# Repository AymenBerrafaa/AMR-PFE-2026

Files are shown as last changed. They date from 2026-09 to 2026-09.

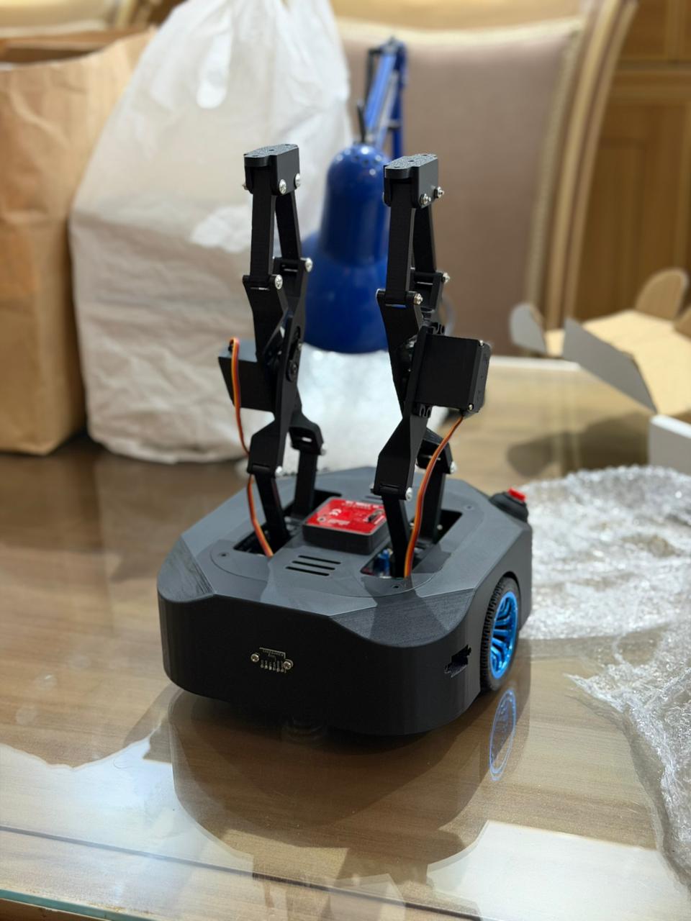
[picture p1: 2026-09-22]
Photos/WhatsApp Image 2026-05-21 at 2.42.04 PM.jpeg

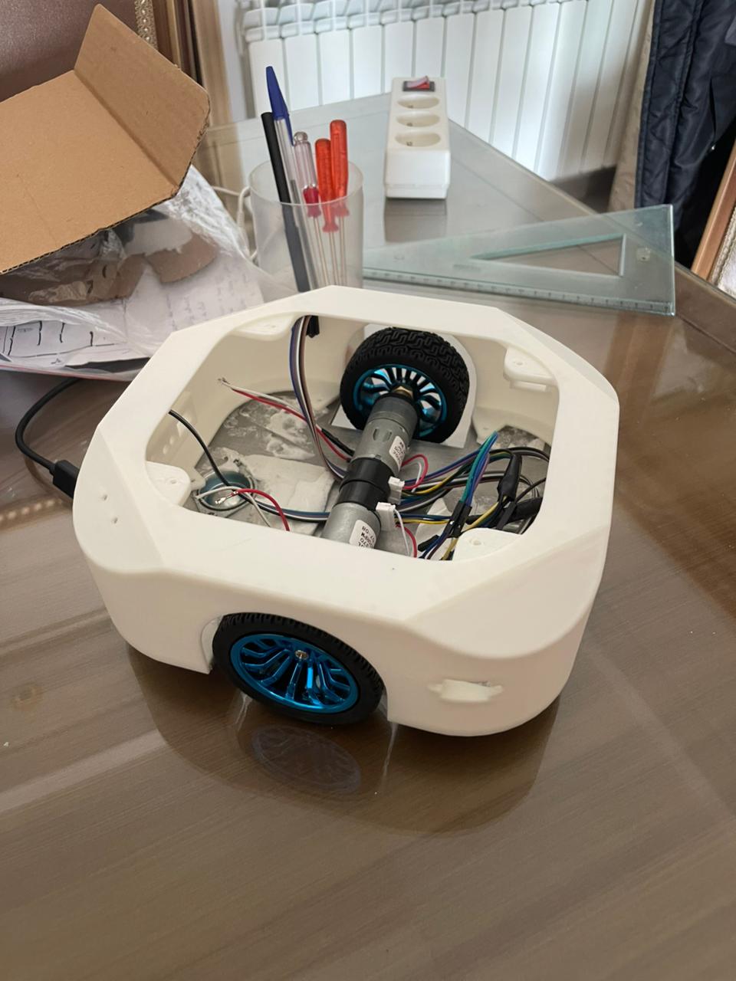
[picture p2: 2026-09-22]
Photos/WhatsApp Image 2026-05-19 at 1.59.03 PM (2).jpeg

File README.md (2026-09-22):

# Autonomous Warehouse AMR — Industrie 4.0

An autonomous mobile robot (AMR) designed for smart warehouse logistics and material transportation. The robot autonomously navigates a grid-based warehouse environment, detects obstacles and walls, plans optimal paths, and performs automated delivery tasks.

Built around an ESP32-S3, the system combines distance sensing, wheel odometry, inertial orientation, RFID identification, motor control, and a real-time web dashboard into a single autonomous platform.

WhatsApp Image 2026-05-26 at 4 40 33 PM WhatsApp Image 2026-05-26 at 2 25 29 PM (1)



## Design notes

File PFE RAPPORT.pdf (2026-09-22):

Rapport de Stage de Fin
d’Etudes

A .U : 2025 / 2026

République Tunisienne
Ministère de l’Enseignement Supérieur,
et de la Recherche Scientifique

Université de Gabès
Institut Supérieur des Systèmes Industriels de Gabès

# RAPPORT PFE

Présenté à

### l’Institut Supérieur des Systèmes Industriels de Gabès

### Dans la discipline

# LICENCE EN EEA

## Spécialité : Systèmes Automatisés et Réseaux Industriels

Réalisé(e) Par

## BERRAFAA Aymen

## Sujet : Etude, Conception et Réalisation d'un prototype de robot mobile autonome pour la

logistique en entrepôt.

Soutenu le 17 juin 2026, devant le jury composé de :

Mme. Hanen CHAOUCH (Maître de conférences) | Président
Mme. Rim KILANI (Maître-assistante) | Rapporteur
Mme. Rafika HARABI (Assistante) | Encadreur

Je dédie ce projet :

Je dédie ce projet, fruit de vos sacrifices, de vos prières silencieuses et de vos nuits sans sommeil. Merci pour votre amour inconditionnel et pour vos conseils qui ont guidé mes pas. Vous avez été ma lumière dans les moments d’incertitude, et c’est grâce à votre soutien que j’ai pu surmonter chaque obstacle. Ce succès est autant le vôtre que le mien.
A mon frère Ahmed,

Merci d'être le pilier que tu es pour moi. Pour ton écoute, tes encouragements et même tes remarques qui m'ont fait grandir. Tu restes mon meilleur allié et un exemple de réussite. Que ce projet soit un témoignage de ma gratitude envers toi.

A mes chères sœurs Mariem, Zaineb et Malak,

Votre présence a été ma plus grande force. Merci pour vos rires qui ont dissipé mes doutes, pour vos conseils francs qui m'ont guidé, et pour votre soutien inconditionnel dans chaque épreuve. Vos encouragements et votre soutien moral tout au long de mes études ont été ma boussole.

A toute ma famille,

A tous mes autres ami(e)s,

A tous ceux que j’aime et ceux qui m’aiment.

, Aymen

# Remerciements

Avant de commencer la présentation de ce rapport, je tiens à exprimer ma profonde

gratitude envers Dieu Tout-Puissant, qui m’a accordé la force, la santé et la persévérance

nécessaires pour mener à bien ma période de stage et finaliser ce projet.

Je tiens à remercier sincèrement Madame Rafika HARABI, mon encadrante universitaire,

pour son accompagnement précieux, ses conseils éclairés et sa disponibilité tout au long de

cette expérience. Son encadrement rigoureux et bienveillant a été un véritable soutien dans la

réalisation de ce travail.

Je remercie également Monsieur Hafedh YAHMED, mon encadrant professionnel, pour

son accueil chaleureux au sein de l’entreprise, ainsi que pour ses orientations pertinentes et

les moyens mis à ma disposition tout au long de cette expérience professionnelle.

Ma gratitude va également à l’ensemble de l’équipe de la société RMG, pour leur accueil,

leur collaboration et l’environnement de travail motivant qu’ils ont su créer. Cette expérience

a été pour moi particulièrement enrichissante, tant sur le plan technique que personnel.

Enfin, je tiens à remercier chaleureusement les membres du jury pour l’attention qu’ils

porteront à l’évaluation de ce travail, ainsi que tous les enseignants de l’Institut supérieur des

systèmes industriels de Gabès pour la qualité de leur enseignement, leur accompagnement et

leur contribution à ma formation tout au long de mon parcours académique.

# Sommaire

3.1.8. Module NFC/RFID PN532 | 52
3.1.9. Régulateur abaisseur LM2596 | 53
3.1.10. Moteur JGA25-370 12V 500 RPM avec encodeur | 54
3.1.11. Batterie Li-ion 18650 Samsung 3400 mAh avec BMS 3S | 55
4. Conception mécanique | 56
4.1. Présentation de système sur le logiciel « SolidWorks » | 56
4.2. Conception du robot | 56
4.3. Conception du mécanisme de levage | 58
4.4. Conception du support de la maquette | 59
5. Conception logicielle | 60
5.1. Organisation des tâches | 60
5.2. Asservissement par correcteur PID | 61
5.2.1. Modélisation et schéma fonctionnel | 62
5.2.2. Correcteur PID et choix retenu | 62
5.3. Gestion de la batterie et retour station | 64
5.4. Communication et supervision | 64
6. Algorithme de fonctionnement | 65
6.1. Étude comparative des algorithmes de navigation | 65
6.1.1. Algorithme Flood Fill | 65
6.1.2. Algorithme A* | 66
6.1.3. Algorithme Dijkstra | 67
6.1.4. Algorithme SLAM | 67
6.2. Algorithme de navigation | 69
7. Dimensionnement du système | 76
7.1. Paramètres cinématiques de déplacement | 76
7.1.1. Vitesse linéaire de navigation | 76
7.1.2. Résolution odométrique | 76
7.1.3. Précision angulaire | 77
7.2. Dimensionnement mécanique | 78
7.2.1. Estimation de la masse totale | 78
7.2.2. Vérification de la force de traction | 79
7.3. Dimensionnement du mécanisme de levage | 79
7.3.1. Géométrie du mécanisme en ciseaux | 79
7.3.2. Analyse des forces et validation du servomoteur | 80
7.4. Bilan de puissance et autonomie | 81
7.4.1. Puissance consommée par sous-système | 81

7.4.2. Calcul de l'autonomie | 82
7.5. Vérification de la stabilité statique | 83
7.6. Récapitulatif général du dimensionnement | 84
8. Conclusion | 84
CHAPITRE IV : Réalisation et étude économique | 86
1. Introduction | 86
2. Réalisation du prototype | 86
2.1. Présentation du prototype | 86
2.2. Assemblage mécanique | 87
2.2.1. Fabrication du châssis | 87
2.2.2. Impression 3D du cadre supérieur | 87
2.2.3. Intégration des moteurs et des roues | 89
2.2.4. Mécanisme de levage en ciseaux | 89
2.2.5. Impression 3D des connecteurs de maquette | 91
2.3. Intégration électronique | 92
2.3.1. Réalisation de la carte électronique dédiée | 92
2.3.2. Raccordement des capteurs et actionneurs | 94
2.3.3. Gestion de l'alimentation | 94
2.4. Vue d'ensemble du prototype assemblé | 95
2.5. Interface de supervision | 96
2.5.1. Architecture de l'interface | 96
2.5.2. Panneau de navigation et de cartographie | 97
2.5.3. Panneau de télémétrie et de sécurité | 98
2.5.4. Journal d'événements | 99
3. Validation et tests | 99
3.1. Tests de déplacement | 99
3.2. Tests de détection d'obstacles | 100
3.3. Tests de sécurité environnementale | 101
3.4. Résultats obtenus | 101
4. Difficultés rencontrées et solutions | 102
4.1. Problèmes matériels | 102
4.2. Problèmes logiciels | 102
5. Étude économique | 103
5.1. Analyse économique | 104
6. Conclusion | 105
Conclusion générale | 107

# Liste des figures

Figure 44 : Régulateur abaisseur LM2596 | 53
Figure 45 : Schéma de Brochage du LM2596 | 53
Figure 46 : Schéma de Brochage du moteur | 54
Figure 47 : Moteur JGA25-370 12V 500 RPM avec encodeur | 54
Figure 48 : BMS 3S | 55
Figure 49 : Support Batterie | 55
Figure 50 : Batterie Li-ion 18650 Samsung 3400 mAh 8A | 55
Figure 51 : Interface SolidWorks | 56
Figure 52 : Châssis principal | 57
Figure 53 : Dimensionnement de châssis principal | 57
Figure 54 : Le cadre supérieur du robot | 57
Figure 55 : Modélisation mécanique | 58
Figure 56 : Pièce centrale inférieure (3) | 58
Figure 57 : Bras gauche (2) | 58
Figure 58 : Pièce centrale | 58
Figure 59 : Base de fixation | 58
Figure 60 : Support haut/bas (1) | 58
Figure 61 : Bras droit (2) | 58
Figure 62 : Panneaux MDF | 59
Figure 63 : Maquette 4×4 | 59
Figure 64 : Connecteur d’angle | 59
Figure 65 : Connecteur en T | 59
Figure 66 : Connecteur droit | 59
Figure 67 : Architecture logicielle multicouche du robot | 60
Figure 68 : Initialisation et cartographie de l’entrepôt | 72
Figure 69 : Boucle de mission logistique (partie 1/2) | 73
Figure 70 : Boucle de mission logistique (partie 2/2) | 74
Figure 71 : Sécurité et supervision parallèles | 75
Figure 72 : Le prototype modélisé sous SolidWorks | 86
Figure 73 : Châssis aluminium usiné | 87
Figure 74 : vue de dessus avec alésages moteurs et roues folles | 87
Figure 75 : Cadre supérieur après peinture | 88
Figure 76 : Cadre supérieur imprimé (vue brute après impression) | 88
Figure 77 : Préparation du slicing sous Creality Slicer | 88
Figure 78 : Intégration des moteurs et des roues sur le châssis | 89
Figure 79 : Mécanisme de levage en ciseaux | 90
Figure 80 : Position haute | 90
Figure 81 : Position basse | 90
Figure 82 : Connecteurs de maquette | 91
Figure 83 : La maquette d'expérimentation 4×4 assemblée | 91
Figure 84 : PCB dédié conçu sous Altium Designer | 92
Figure 85 : Face supérieure de la carte | 93
Figure 86 : Intégration électronique du robot | 94
Figure 87 : Vue de côté avec mécanisme de levage | 95
Figure 88 : Vue de dessus - intégration interne | 95

Figure 89 : Vue du robot assemblé | 96
Figure 90 : Vue générale du tableau de bord de supervision | 97
Figure 91 : Panneau de cartographie et visualisation de la grille 4×4 | 98
Figure 92 : Panneau de télémétrie et de sécurité environnementale | 98
Figure 93 : Panneau de journal d'événements | 99
Figure 94 : Robot lors des tests de déplacement sur la maquette | 100
Figure 95 : Robot en cours de validation des capteurs | 100
Figure 96 : Test de sécurité environnementale | 101

# Liste des tableaux

# Liste des abréviations

AGV : Automated Guided Vehicle (Véhicule à Guidage Automatique)

AMR : Autonomous Mobile Robot (Robot Mobile Autonome)

ADC : Analog-to-Digital Converter (Convertisseur Analogique-Numérique)

BFS : Breadth-First Search (Parcours en Largeur d'abord) – algorithme d'exploration

BMS : Battery Management System (Système de Gestion de Batterie)

CAO : Conception Assistée par Ordinateur

CNC : Computer Numerical Control (Commande Numérique par Calculateur)

CPR : Counts Per Revolution (Impulsions Par Tour) – résolution d'un encodeur

DC : Direct Current (Courant Continu)

DFS : Depth-First Search (Parcours en Profondeur d'abord) – algorithme d'exploration

DXF : Drawing Exchange Format – format d'échange de fichiers CAO 2D

ESP32 : Microcontrôleur double cœur Xtensa LX7 @ 240 MHz développé par Espressif Systems

FAST : Function Analysis System Technique – méthode d'analyse fonctionnelle interne

FreeRTOS : Free Real-Time Operating System – système d'exploitation temps réel open source

GPIO : General Purpose Input/Output (Entrée/Sortie à Usage Général)

GPL : Gaz de Pétrole Liquéfié – gaz détecté par le capteur MQ-5

HAL : Hardware Abstraction Layer (Couche d'Abstraction Matérielle)

HTML : HyperText Markup Language – langage de balisage pour les interfaces web

I²C : Inter-Integrated Circuit – protocole de communication série synchrone (bus 2 fils)

IDE : Integrated Development Environment (Environnement de Développement Intégré)

IMU : Inertial Measurement Unit (Centrale Inertielle) – capteur accéléromètre + gyroscope

IoT : Internet of Things (Internet des Objets)

ISR : Interrupt Service Routine (Routine de Traitement d'Interruption)

JSON : JavaScript Object Notation – format léger d'échange de données

LED : Light-Emitting Diode (Diode Électroluminescente)

LIDAR : Light Detection And Ranging – capteur de distance à faisceau laser tournant

MDF : Medium-Density Fibreboard (Panneau de Fibre à Densité Moyenne)

MQTT : Message Queuing Telemetry Transport – protocole de messagerie machine-à-machine

NFC : Near Field Communication (Communication en Champ Proche)

PCB : Printed Circuit Board (Circuit Imprimé)

PETG : Polyethylene Terephthalate Glycol – matériau d'impression 3D résistant et flexible

PID : Proportionnel-Intégral-Dérivé – correcteur de régulation automatique

PLA : Polylactic Acid (Acide Polylactique) – matériau d'impression 3D biodégradable

PSRAM : Pseudo-Static RAM – mémoire RAM externe pseudo-statique intégrée à l'ESP32-S3

PWM : Pulse Width Modulation (Modulation de Largeur d'Impulsion)

RAM : Random Access Memory (Mémoire Vive)

RFID : Radio Frequency Identification (Identification par Radio-Fréquence)

RMG : Rebobinage Moteur & Groupe Électrogène Gabès – entreprise d'accueil du stage

ROS : Robot Operating System – système d'exploitation pour la robotique

RPM : Revolutions Per Minute (Tours Par Minute)

SAV : Service Après-Vente

SLAM : Simultaneous Localization And Mapping (Localisation et Cartographie Simultanées)

SPI : Serial Peripheral Interface – protocole de communication série synchrone (bus 4 fils)

SRAM : Static Random Access Memory (Mémoire Vive Statique)

SSID : Service Set Identifier – nom d'un réseau Wi-Fi

ToF : Time of Flight (Temps de Vol) – technologie de mesure de distance laser

UART : Universal Asynchronous Receiver-Transmitter – protocole de communication série asynchrone

URL : Uniform Resource Locator – adresse d'une ressource sur le web

USB : Universal Serial Bus – interface de connexion et d'alimentation

Wi-Fi : Wireless Fidelity – réseau local sans fil IEEE 802.11

WMS : Warehouse Management System (Système de Gestion d'Entrepôt)

# Introduction générale

Introduction générale

Etude, conception et réalisation d'un prototype de robot mobile autonome pour la logistique en entrepôt

# Introduction générale

L’évolution constante de l’industrie 4.0 impose aujourd’hui une gestion des flux de

marchandises de plus en plus rapide et précise. Dans ce contexte, la manutention manuelle et

le transport interne de matériel représentent des défis opérationnels majeurs, impactant

directement la productivité et la sécurité. Le déplacement répétitif de charges lourdes prend du

temps, fatigue physiquement les opérateurs et accroît le risque d'accidents du travail.

Au sein des centres logistiques modernes, l’enjeu n'est plus seulement de déplacer une

charge, mais d'optimiser le flux tout en garantissant une sécurité totale. Les méthodes de

transport traditionnelles manquent souvent de flexibilité et de réactivité face aux changements

dynamiques de l’environnement. Dès lors, l’intégration de la robotique mobile autonome

devient une solution incontournable pour fluidifier la logistique, réduire la pénibilité des tâches

et assurer une surveillance constante des zones de stockage.
Ce Projet de Fin d’Études, réalisé en partenariat avec la société 'RMG', a pour but de

concevoir et réaliser un prototype de robot mobile autonome capable de naviguer de manière

intelligente, de cartographier son environnement et d'assurer le transfert de marchandises en

toute autonomie. Au-delà du simple transport, ce prototype intègre des fonctionnalités de

supervision avancées, telles que la gestion intelligente de l'énergie et la surveillance de

paramètres environnementaux (détection de gaz, incendie et température) pour garantir la

sécurité des infrastructures.

Ce rapport est organisé en quatre chapitres, précédés de la présentation de l'entreprise

d'accueil 'RMG' et du cahier des charges, et clôturés par une conclusion générale. Le premier

chapitre présente l'étude bibliographique des robots mobiles industriels et autonomes, ainsi

qu'un état de l'art des technologies de navigation indoor. Le deuxième chapitre est consacré à

l'analyse fonctionnelle du système et au choix justifié des solutions techniques retenues. Le

troisième chapitre détaille l'étude et la conception du prototype, en couvrant l'architecture

matérielle et logicielle, ainsi que le dimensionnement complet du système. Le quatrième

chapitre présente la réalisation physique du prototype, les tests de validation effectués sur la

maquette 4×4, l'analyse des résultats obtenus ainsi que l'étude économique du projet.

# Présentation de la société

Présentation de la société

# Présentation de la société

## 1. Présentation Générale de l'Entreprise

RMG est une entreprise tunisienne spécialisée dans le domaine de la maintenance

électromécanique, notamment la fabrication, le bobinage et le rebobinage de moteurs et de

générateurs, basée à Gabès. Depuis sa création, RMG joue un rôle important dans le secteur

industriel tunisien, contribuant à la pérennité des équipements électriques et à la promotion

d’une infrastructure de qualité. Son expérience témoigne de sa fiabilité et de son engagement

envers l’innovation et la performance technique au service de l'industrie. Elle est située à la

Rue Elwehda, dans le gouvernorat de Gabes (6000). Avec une expertise solide dans son

domaine, RMG fournit des services de haute qualité aux professionnels. L’entreprise peut être

contactée par téléphone au 58 821 009, par fax au 74 299 650, permet également de découvrir

ses produits et services.

## 2. Activités et Produits

L'activité de RMG s'articule autour de solutions techniques complètes pour les machines

électriques, allant du diagnostic à la remise en neuf. Ses principales expertises incluent :

Bobinage et Rebobinage : Remise en état complète des bobinages de moteurs électriques

(BT/HT), d'alternateurs et de transformateurs, en respectant les classes d'isolation les plus

strictes.
Maintenance Électromécanique : Diagnostic de pannes, expertise mécanique, équilibrage

dynamique et remplacement de pièces d’usure (roulements, arbres, ventilateurs).

Fabrication et Montage : Conception de solutions spécifiques et assemblage de moteurs

ou de générateurs adaptés aux besoins des clients industriels.

Figure 1 : Logo de RMG

Présentation de la société

Vente et Distribution : Fourniture de moteurs neufs et de pièces de rechange certifiées

pour assurer la continuité de service des parcs machines.

RMG collabore avec des partenaires technologiques pour garantir des matériaux (fil de

cuivre, isolants, vernis) répondant aux normes internationales de sécurité et de rendement.

## 3. Marché et Positionnement

RMG cible principalement trois segments clés du marché tunisien : les complexes

industriels lourds (cimenteries, usines chimiques), les entreprises de gestion des eaux et de

l'énergie, ainsi que les exploitations agricoles mécanisées. Cette diversification de clientèle lui

permet de couvrir un large spectre de besoins en maintenance, en bobinage et en fourniture de

machines électriques.

Sur un marché concurrentiel, RMG se distingue par son expertise technique et ses

partenariats avec des fournisseurs de composants électromécaniques. Elle fait face à la

concurrence d’autres ateliers de maintenance locaux, ainsi qu’à la pression des constructeurs

internationaux de moteurs qui opèrent directement en Tunisie. Pour maintenir son

positionnement, l’entreprise mise sur la qualité de ses interventions, la fiabilité de ses services

après-vente (SAV) et sa capacité à répondre aux exigences spécifiques des professionnels de

l'industrie et de la production d'énergie.

Cette stratégie lui permet de se positionner comme un acteur crédible et compétitif dans un

secteur en constante évolution, où la performance technique et la réactivité jouent un rôle

déterminant dans le choix des partenaires.

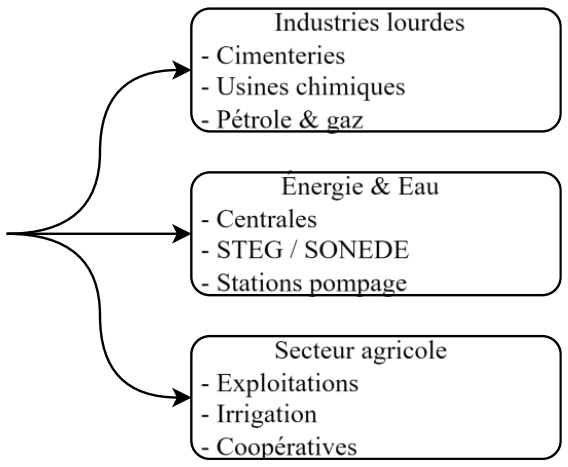
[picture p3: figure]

Figure 2 : Principaux marchés cibles de RMG

# Cahier des charges

Cahier Des Charges

# CAHIER DES CHARGES

## Sujet :

Etude, conception et réalisation d'un prototype de robot mobile autonome pour la logistique

en entrepôt.

## Objectif :

L'objectif principal de ce projet est de développer un prototype de robot capable de :

Automatiser le transport de marchandises entre différentes zones (stockage, réception) pour

fluidifier la logistique.

Reconnaître et mémoriser son environnement de manière autonome afin d'optimiser ses

déplacements.

Garantir une sécurité totale grâce à la surveillance environnementale (détection de gaz,

incendie et température).

Assurer une gestion intelligente de l'énergie via un système de recharge automatique et une

supervision en temps réel.

## Travail demandé :

- Étude approfondie des besoins logistiques en milieu industriel, en prenant en compte

les types de charges à transporter et les contraintes de navigation en espace restreint.

- Recherche et sélection des technologies de navigation (capteurs, cartographie) et de

traction les plus appropriées, en tenant compte de leur efficacité, durabilité et coût.

- Conception du robot sur le logiciel SolidWorks.
- La configuration mécanique et électronique.
- Intégration des algorithmes d’automatisation, de cartographie et de missions.
- Réalisation d'un prototype fonctionnel, avec des tests approfondis pour vérifier la

précision de la navigation et la fiabilité du transport.

- Mise en place d'un système de supervision et de communication entre l’utilisateur et le

robot (interface de suivi, Wi-Fi, etc.).

- Documentation de toutes les étapes du projet (Les spécifications techniques, les

résultats des tests, les schémas de conception, etc.).

# CHAPITRE Ⅰ : Étude bibliographique

Etude Bibliographique

# CHAPITRE Ⅰ : Étude bibliographique

## 1. Introduction

Cette étude explore les solutions automatisées pour le transport de charges industrielles,

telles que les Robots Mobiles Autonomes, afin d’offrir une alternative efficace et sécurisée aux

méthodes de manutention manuelles. Bien que la robotique mobile gagne en popularité dans

les domaines logistiques, manufacturiers et de maintenance, des défis persistent : l'optimisation

de la navigation autonome, la gestion énergétique en flux continu et l'adaptation aux

environnements encombrés des entrepôts.

L’objectif est d’analyser les technologies existantes, leurs limites et les innovations

potentielles pour concevoir un prototype robuste et polyvalent. Ce chapitre synthétise les

solutions actuelles, les technologies émergentes de navigation et les meilleures pratiques

industrielles, afin de guider le développement d’un robot fiable, réduisant la pénibilité du travail

et les risques d’incidents matériels.

## 2. Généralités sur les robots mobiles autonomes

### 2.1. Définition d'un robot mobile autonome (AMR)

Le robot mobile autonome est un système automatisé intelligent conçu pour transporter et

manœuvrer des charges dans des environnements dynamiques sans intervention humaine

constante [1]. Contrairement aux systèmes guidés simples, l'AMR utilise des capteurs de

précision (LIDAR, ultrasons, infrarouge) et des algorithmes de cartographie avancés pour

calculer ses propres trajectoires. Ses principaux atouts incluent une flexibilité totale face aux

obstacles, une grande maniabilité dans les espaces restreints des ateliers, ainsi qu'une interface

logicielle permettant un suivi en temps réel.

Ce type de robot trouve des applications cruciales dans de nombreux secteurs : dans la

logistique pour le déplacement de bacs de pièces, dans l'industrie pour le transfert de moteurs

ou de générateurs entre les zones de stockage et de bobinage, et dans les centres de distribution.

Il offre une solution pratique qui améliore la productivité globale tout en garantissant une

sécurité accrue grâce à ses systèmes de détection intégrés.

Etude Bibliographique

### 2.2. Historique des robots mobiles

L’histoire de la mécanisation du transport remonte à l’ère industrielle, lorsque les premiers

convoyeurs et chariots motorisés ont commencé à soulager l’homme des travaux de force. Les

premières innovations du 19ème siècle, bien qu'efficaces pour l'époque, restaient des machines

massives et fixes, limitées à des tâches répétitives sur rails.

Le début du 20ème siècle a marqué une révolution avec l’électrification des chariots

élévateurs, permettant une mobilité accrue dans les usines. Vers le milieu du siècle, les premiers

AGV (Automated Guided Vehicles) ont fait leur apparition, capables de suivre des lignes

magnétiques ou des câbles enterrés. Aujourd’hui, les AMR comme celui développé pour ce

projet incarnent l’aboutissement de cette évolution. Dotés d’intelligence artificielle et d’une

autonomie décisionnelle complète, ils répondent avec précision aux besoins de l'industrie 4.0.

### 2.3. Constituants d'un robot mobile autonome

Un robot mobile est un système complexe composé de plusieurs sous-systèmes [1] qui

travaillent en synergie pour garantir ses performances :

1) Système de traction :

Le robot utilise des moteurs électriques haute performance offrant un couple élevé et

une excellente efficacité énergétique pour déplacer des charges lourdes. La transmission

mécanique optimise le transfert de puissance vers les roues, garantissant une traction fiable

et économe en énergie.

Figure 3 : Robot mobile autonome

Etude Bibliographique

2) Système de mobilité :

L'architecture intègre des roues motorisées permettant des manœuvres précises dans

les espaces confinés. La configuration peut varier selon le terrain (roues standards ou

omnidirectionnelles).

3) Système de contrôle :

Le robot est piloté par une unité centrale équipée de processeurs embarqués

performants qui coordonnent l'ensemble des opérations. Des algorithmes avancés de

navigation lui permettent d'analyser son environnement en temps réel et d'ajuster sa

trajectoire de manière autonome.

4) Système de détection :

Le robot s'appuie sur une combinaison de capteurs (LIDAR, ultrasons, infrarouge)

pour cartographier son environnement et éviter les obstacles avec précision. Des caméras

haute résolution complètent ce système en offrant une vision en temps réel et en permettant

des fonctions avancées comme la reconnaissance d'objets ou le suivi de balises,

garantissant une navigation sécurisée et autonome dans des environnements complexes.

5) Source d'énergie :

Le robot est équipé de batteries lithium-ion haute performance offrant une autonomie

optimale, couplées à un système de gestion énergétique (BMS) qui régule précisément la

consommation et protège contre les surcharges.

6) Système d'interfaçage :

Le système propose une interface intuitive via écran tactile ou application mobile,

permettant un contrôle aisé et un suivi en temps réel des opérations. La connectivité sans

fil (Wi-Fi/Bluetooth) assure une communication fluide avec les opérateurs et une parfaite

intégration dans les écosystèmes logistiques intelligents.

### 2.4. Les types de robots de transport industriel

Les robots de transport sont conçus pour déplacer des charges, comme des bacs, des

palettes ou des composants. Ces robots se différencient par leurs technologies, leurs capacités

et leurs applications. Voici une classification des principaux types de robots utilisés :

Etude Bibliographique

### 2.4.1. Robots de manutention assistés (semi-automatique)

Ces robots nécessitent une intervention humaine pour leur guidage, mais ils fournissent une

assistance motorisée pour réduire l’effort physique.

- Caractéristiques :

Ces systèmes d'assistance électrique offrent une solution simple et économique pour

déplacer des charges lourdes allant de 500 kg à 2 000 kg. Particulièrement adaptés aux

environnements industriels comme les entrepôts, ils combinent puissance et efficacité pour

faciliter les opérations de manutention tout en réduisant l'effort physique requis.

Exemple et utilisation : Transpalettes électriques à accompagnement : Un système manuel

assisté pour déplacer des palettes en zone de réception.

Avantages et limitations fonctionnelles :

Les systèmes semi-automatisés présentent des caractéristiques fonctionnelles notables.

D'une part, ils permettent une réduction substantielle de la sollicitation physique des opérateurs

lors des opérations de manutention, tout en offrant une interface de contrôle intuitive ne

nécessitant qu'une formation minimale. Leur architecture mécanique simplifiée se traduit par

des coûts d'acquisition et de maintenance inférieurs aux solutions entièrement automatisées.

D'autre part, ces systèmes présentent des limitations opérationnelles significatives. Leur

fonctionnement requiert une supervision humaine continue et leur capacité de charge reste

inférieure à celle des systèmes robotisés avancés. Par ailleurs, leur performance est optimale

Figure 4 : Chariot élévateur semi-automatique

Etude Bibliographique

sur surfaces planes et régulières, avec une efficacité décroissante dans des environnements

topographiquement complexes.

- Prix et facteurs d’influence

De 1 500 € à 5 000 €. Les facteurs influençant le prix sont la capacité de charge, l'autonomie

de la batterie et la marque du fabricant (ex : Toyota, Jungheinrich).

### 2.4.2. Robots de manutention télécommandés

Ces robots sont pilotés à distance par un opérateur via une console de commande. Ils

permettent de manipuler des charges lourdes dans des zones étroites ou dangereuses sans

contact direct.

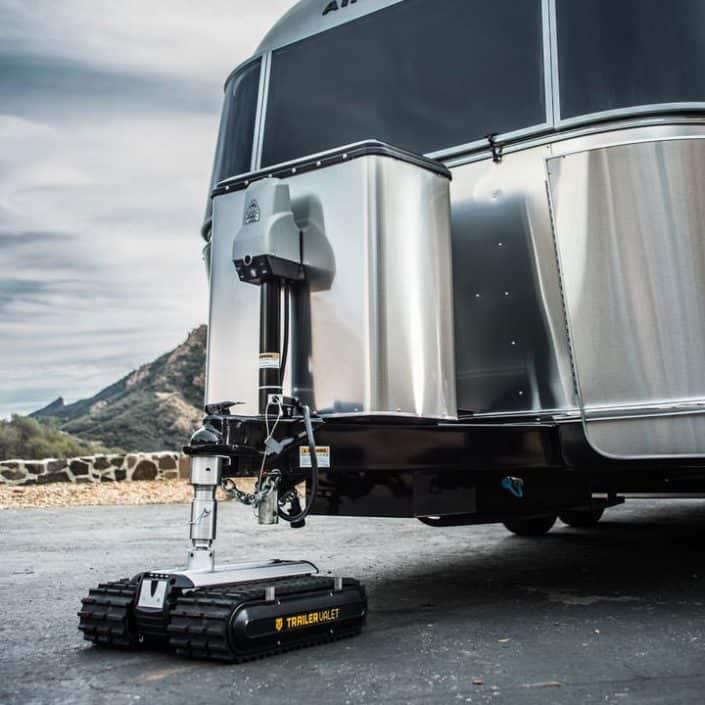
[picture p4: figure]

Figure 5 : Robots de traction télécommandés

- Caractéristiques techniques et applications

Ces systèmes se distinguent par leur capacité à opérer à distance via différents protocoles

de communication (Wi-Fi, Bluetooth, radiofréquence), tout en conservant une excellente

adaptabilité aux divers types de terrains. Leur conception mécanique avancée permet la

manipulation de charges substantielles (500 à 5000 kg) avec une précision de manœuvre

remarquable, particulièrement dans des espaces confinés.

Ces systèmes robotisés trouvent leur utilité dans plusieurs contextes opérationnels. Leurs

caractéristiques techniques les rendent particulièrement adaptés à :

Etude Bibliographique

- Manutention logistique : Déplacement précis de remorques en espaces restreints (zones

de chargement, centres logistiques)

- Secteur nautique/camping : Positionnement de bateaux/caravanes sur terrains accidentés
- Chantiers industriels : Manipulation d'équipements lourds (jusqu'à 5 tonnes) là où les

engins traditionnels peinent à manœuvrer

Exemple : Trailer Valet RVR

- Avantages et limites :

Les robots de traction télécommandés offrent des avantages significatifs, notamment un

contrôle précis particulièrement adapté aux espaces restreints, une capacité à tracter des charges

lourdes jusqu'à plusieurs tonnes, et une grande polyvalence d'utilisation sur différents types de

terrains. Leur conception compacte facilite par ailleurs leur transport et leur déploiement sur

divers sites.

Cependant, ces systèmes présentent certaines limitations : ils dépendent entièrement de leur

télécommande, nécessitant ainsi une gestion attentive des batteries, et peuvent s'avérer difficiles

à manipuler. De plus, leur coût d'acquisition reste plus élevé que celui des modèles manuels

assistés.

- Prix et facteurs d’influence :

De 5 000 € à 15 000 € les facteurs influençant le prix sont (Puissance de traction (capacité

en kg), Technologie de télécommande (filaire ou sans fil), Robustesse et durabilité (militaire

ou civil).

### 2.4.3. Véhicules à Guidage Automatique (AGV)

Les AGV suivent des chemins fixes prédéfinis par des infrastructures au sol (bandes

magnétiques, rails ou balises), pour fonctionner sans intervention humaine directe. Ils

constituent une solution standard pour le transport de charges lourdes

Etude Bibliographique

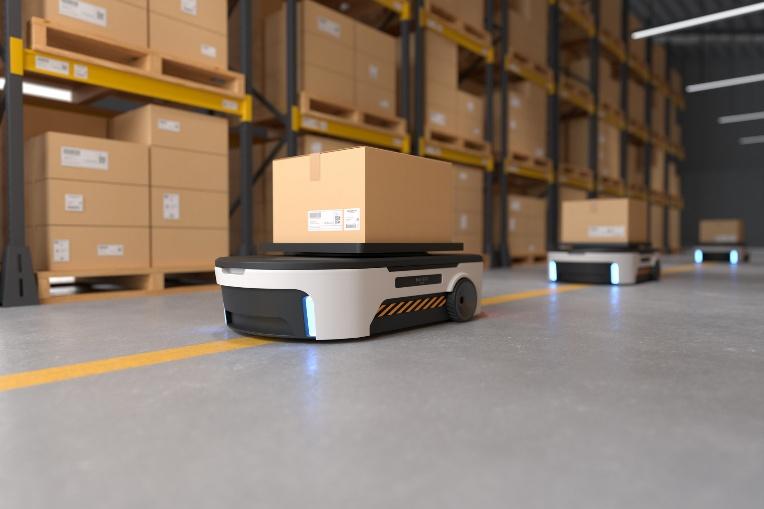
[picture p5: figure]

Figure 6 : AGV industriel suivant une ligne magnétique

- Caractéristiques techniques et applications

Ces systèmes se distinguent par leur navigation dépendante d’une infrastructure physique

au sol (bandes magnétiques, rails, fils inductifs ou balises laser). Leur conception mécanique

est optimisée pour la stabilité et la puissance de traction (500 kg à 10 tonnes).

Les AGV trouvent leur utilité principale dans :

- Lignes de production : Transport de composants entre des stations de travail fixes.
- Entrepôts automatisés : Déplacement de palettes lourdes sur des boucles prédéfinies.
- Secteur automobile : Acheminement de châssis le long des chaînes d'assemblage.
- Exemple : Kiva Systems (premières générations), AGV à guidage par bande magnétique.
- Avantages et limites :

Les AGV offrent une grande fiabilité et une excellente répétabilité pour les tâches simples.

Ils permettent de sécuriser les flux de transport massifs à un coût de maintenance prévisible.

Cependant, ils manquent de flexibilité : toute modification du trajet nécessite des travaux

coûteux sur l'infrastructure. De plus, ils s'arrêtent net devant un obstacle sans pouvoir le

contourner, ce qui peut paralyser l'ensemble du flux logistique.

- Prix et facteurs d’influence :

De 15 000 € à 45 000 €. Les facteurs influençant le prix sont la capacité de charge, le type

d'infrastructure de guidage requis et les dispositifs de sécurité (scanners laser).

Etude Bibliographique

### 2.4.4. Robots Mobiles Autonomes (AMR)

L'AMR constitue une rupture technologique majeure grâce à son intelligence embarquée

et sa capacité de décision en temps réel.

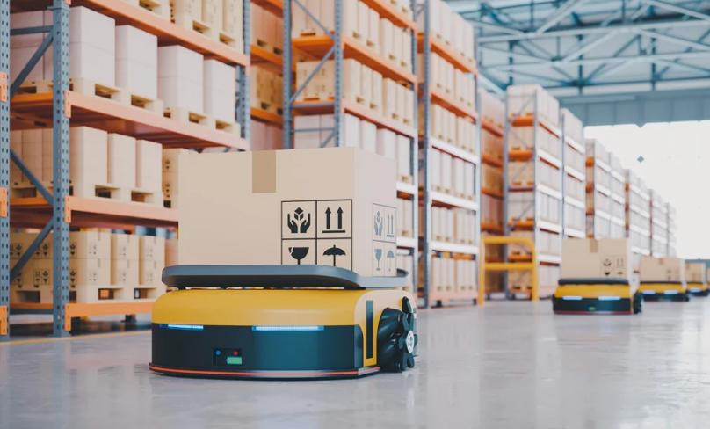
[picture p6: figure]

- Caractéristiques techniques et applications

Ces systèmes intègrent une intelligence artificielle embarquée capable de cartographie

simultanée et de localisation. Ils utilisent une fusion de capteurs avancés (LIDAR, caméras 3D,

ultrasons, encodeurs) pour interpréter leur environnement en temps réel. Leur capacité de

charge varie de 100 kg à 1 500 kg avec une agilité exceptionnelle.

Les AMR sont particulièrement adaptés à :

- Logistique en entrepôt : Gestion autonome des stocks (ajout/retrait) avec mise à jour en

temps réel des bases de données.

- Préparation de commandes : Guidage vers les étagères et transport de bacs dans des allées

encombrées.

- Industrie 4.0 : Transport multisites où le robot doit emprunter des ascenseurs et contourner

des obstacles imprévus (humains, palettes mal placées).

- Exemple : MiR100 (ou MiR250) de la société Mobile Industrial Robots (MiR). [W5]
- Avantages et limites :

L’avantage majeur réside dans la flexibilité totale et la gestion intelligente des

marchandises. Le robot sait précisément ce qu'il transporte, d'où il vient et où il va, surpassant

Figure 7 : AMR logistique intelligent

Etude Bibliographique

la gestion humaine en termes de précision d'inventaire. Il permet un gain de temps considérable

en recalculant instantanément ses trajectoires pour éviter les zones de trafic dense. La limitation

principale reste la complexité logicielle (algorithmes de navigation) et un investissement initial

plus élevé. Cependant, le retour sur investissement est rapide car il ne nécessite aucune

modification des locaux.

- Prix et facteurs d’influence :

De 25 000 € à 80 000 €. Les facteurs influençant le prix sont la puissance de calcul

embarquée, la précision des capteurs (LIDAR 360°), l'autonomie de batterie et l'intégration

logicielle avec les systèmes de gestion d'entrepôt (WMS).

### 2.5. Marché et évolution des robots autonomes d'entrepôt

Le marché des robots mobiles autonomes (AMR) connaît une croissance rapide. En 2024,

il était évalué à environ 344,48 millions USD [12] et devrait atteindre 1 046,96 millions USD

d’ici 2033, avec un taux de croissance annuel composé (TCAC) de 14,91%. Cette croissance

est principalement due à l’augmentation de la demande pour des solutions d'automatisation des

flux dans les zones logistiques, ainsi qu’à l’avancement des technologies de robotique et

d’intelligence artificielle. Les robots AMR sont de plus en plus adoptés dans les infrastructures

industrielles, logistiques et manufacturières pour optimiser l’utilisation de l’espace [11] et

assurer un transport de charges fluide sans infrastructure lourde.

### 2.6. Les difficultés pouvant survenir en absence de ce robot

Sans l’utilisation d’un robot mobile de type AMR, plusieurs problèmes peuvent survenir,

surtout pour les opérateurs qui doivent manœuvrer manuellement des charges ou des

composants lourds. Voici une liste des défis possibles :

### 2.6.1. Difficulté à manœuvrer dans des espaces restreints

- Problème : Les chariots manuels peuvent être difficiles à déplacer dans des allées

étroites, des zones de stockage denses ou des quais de chargement.

- Impact : Risque de collisions avec les rayonnages, d’autres engins de manutention, ou

des infrastructures de l'entrepôt.

Etude Bibliographique

### 2.6.2. Fatigue et effort physique

- Problème : Pousser ou tirer des bacs de pièces manuellement nécessite une force

physique répétitive, surtout pour des charges industrielles importantes.

- Impact : Risque de blessure physique, comme des douleurs musculaires, des tensions,

ou même des accidents.

### 2.6.3. Mauvaise précision de flux et de livraison

- Problème : Lorsque les charges sont déplacées manuellement ou avec des transpalettes

classiques, il est difficile de garantir un timing et un alignement précis.

- Impact : Difficulté à synchroniser l'apport de composants avec les cadences de

production, créant des interruptions de flux.

### 2.6.4. Risque d’accidents

- Problème : Un chariot mal contrôlé par un humain peut glisser, basculer ou heurter des

obstacles imprévus par manque de visibilité.

- Impact : Dommages matériels (aux produits stockés ou au bâtiment) et risques graves

de blessures pour le personnel au sol.

### 2.6.5. Dépendance à une main-d'œuvre multiple

- Problème : Déplacer des unités de stockage massives peut nécessiter plusieurs

opérateurs pour guider, stabiliser ou sécuriser le trajet.

- Impact : Perte de temps et baisse de l’efficacité opérationnelle, particulièrement dans

les environnements de logistique à haute cadence.

### 2.6.6. Manque de visibilité sur l'état des stocks

- Problème : Contrairement à l'AMR, un opérateur humain peut oublier de noter un retrait

ou un ajout de marchandise, rendant le suivi du stock imprécis.

- Impact : Difficulté à aligner l'inventaire réel avec le système informatique, causant des

ruptures de stock ou des surplus inutiles.

Etude Bibliographique

### 2.6.7. Dépendance humaine et erreurs de saisie

- Problème : Déplacer et inventorier des marchandises manuellement nécessite une

attention constante pour ne pas oublier de noter chaque entrée ou sortie de stock.

- Impact : Contrairement à l'AMR qui enregistre numériquement chaque mouvement,

l'humain peut commettre des erreurs de comptage, faussant l'état réel des marchandises

disponibles.

### 2.6.8. Perte de temps

- Problème : Sans un outil motorisé et autonome, les trajets entre les zones de stockage

et de préparation sont lents et répétitifs pour les opérateurs.

- Impact : Cette perte de temps accumulée réduit la cadence de l'entrepôt, là où un robot

pourrait fonctionner en flux continu sans interruption, optimisant chaque seconde de

transport.

### 2.6.9. Manque de traçabilité en temps réel

- Problème : Un opérateur peut déplacer un bac sans que le système informatique ne soit

mis à jour instantanément, créant un décalage d'information.

- Impact : L'AMR surpasse la gestion humaine en sachant exactement quelle marchandise

il a ajoutée ou retirée, éliminant les temps de recherche de produits "perdus" dans

l'entrepôt.

## 3. Conclusion

En conclusion, le Robot Mobile Autonome (AMR) représente une avancée technologique

significative non seulement pour le transport, mais aussi pour la gestion intelligente des

marchandises. Grâce à ses fonctionnalités innovantes telles que la navigation SLAM et son

interfaçage avec les systèmes de gestion de stock (WMS), il offre une solution plus fiable que

l'humain pour le suivi des inventaires en temps réel. En sachant précisément quel produit est

ajouté ou retiré, ce robot permet de surmonter les défis traditionnels liés à la manutention

manuelle, notamment les erreurs de comptage, la fatigue physique et le manque de traçabilité.

En réduisant les erreurs humaines et en augmentant la visibilité sur les stocks, l’AMR améliore

considérablement l'efficacité globale et répond aux besoins de précision de l'industrie 4.0

# Analyse fonctionnelle et choix des solutions

Analyse fonctionnelle et choix des solutions

# CHAPITRE II : Analyse fonctionnelle et choix des solutions

## 1. Introduction

L’analyse fonctionnelle est une méthode structurée pour définir et organiser les fonctions

d’un système. Elle utilise des outils comme le diagramme A-0 le diagramme FAST et le

diagramme de Pieuvre. Ces outils aident à clarifier les besoins, à structurer la réflexion et à

choisir les solutions techniques les plus adaptées. Essentielle en ingénierie et en gestion de

projet, l’analyse fonctionnelle permet de transformer des idées en solutions concrètes et

efficaces.

## 2. Choix de solution

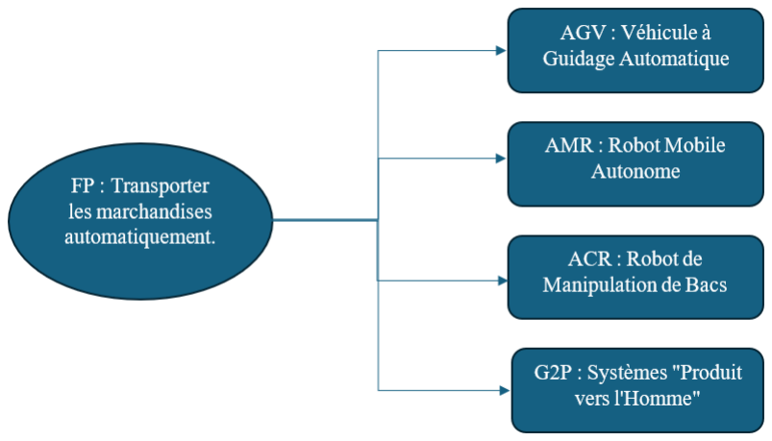
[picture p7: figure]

Figure 8 : les solutions proposées

## 3. Analyse fonctionnelle externe

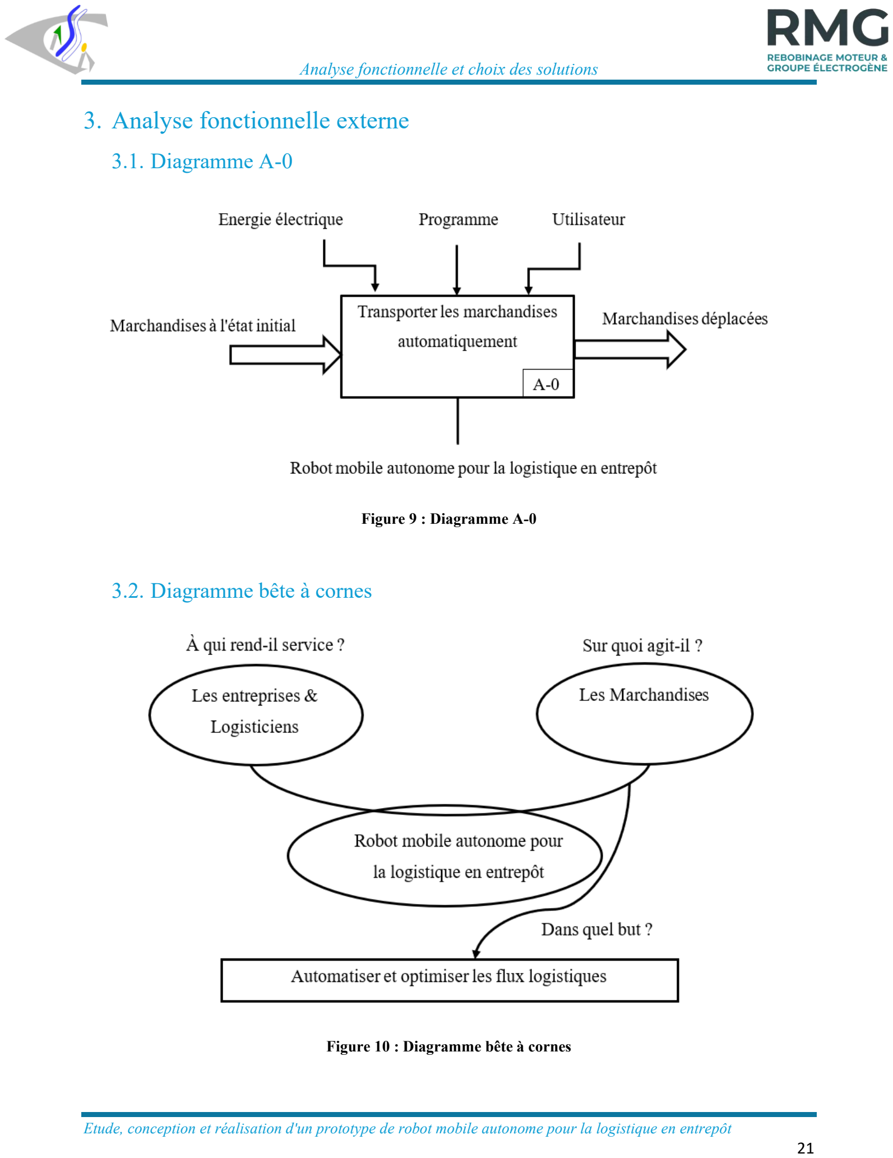
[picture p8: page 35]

Analyse fonctionnelle et choix des solutions

### 3.1. Diagramme A-0

Figure 9 : Diagramme A-0

### 3.2. Diagramme bête à cornes

Figure 10 : Diagramme bête à cornes

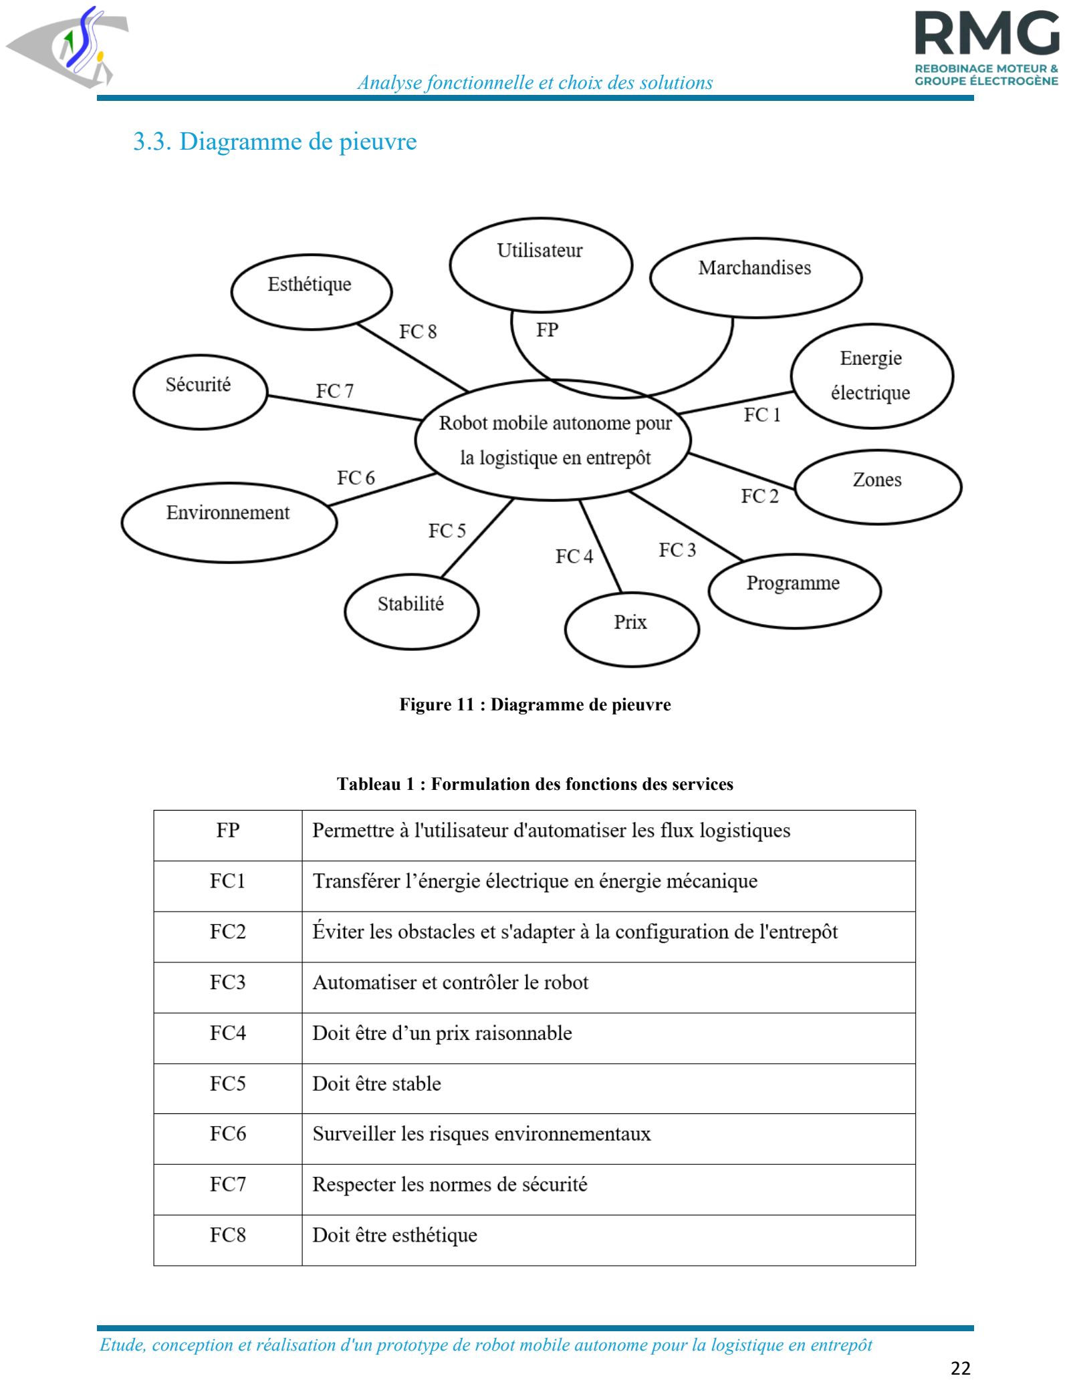
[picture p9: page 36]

Analyse fonctionnelle et choix des solutions

### 3.3. Diagramme de pieuvre

Figure 11 : Diagramme de pieuvre

Tableau 1 : Formulation des fonctions des services

Analyse fonctionnelle et choix des solutions

### 3.4. Tri croisé

Tableau 2 : L'importance des fonctions

Figure 12 : Histogramme

Tableau 3 : Tri croisé

Analyse fonctionnelle et choix des solutions

### 3.5. Rédaction du cahier de charge fonctionnelle

Tableau 4 : Cahier de charge fonctionnelle

F. S | Expression de la fonction de service | Critères d’appréciation | Niveau et flexibilité
FP | Transport autonome | Précision d'arrêt Vitesse | ± 1 cm 0.5 m/s à 1.2 m/s
FC7 | Respecter les normes de sécurité | Protéger les marchandises Protéger les utilisateurs | Bouton d'arrêt d'urgence.
FC1 | Transférer l’énergie électrique en énergie mécanique | Energie | Batterie 12 v
FC6 | Surveiller les risques environnementaux | Seuil Gaz/Incendie Temps d'alerte | 300 ppm GPL 60 °C < 1 seconde
FC5 | Doit être stable | Stabilité dynamique | Absence de basculement.
FC4 | Doit être d’un prix raisonnable | Prix | Maximum 1200TND
FC3 | Automatiser et contrôler le robot | Système de contrôle | Réduire l’effort
FC2 | Éviter les obstacles et s'adapter à la configuration de l'entrepôt | Distance de détection Angle de couverture | Faible latence
FC8 | Doit être esthétique | Design, finition | Matériaux de qualité, esthétique

## 4. Analyse fonctionnelle interne

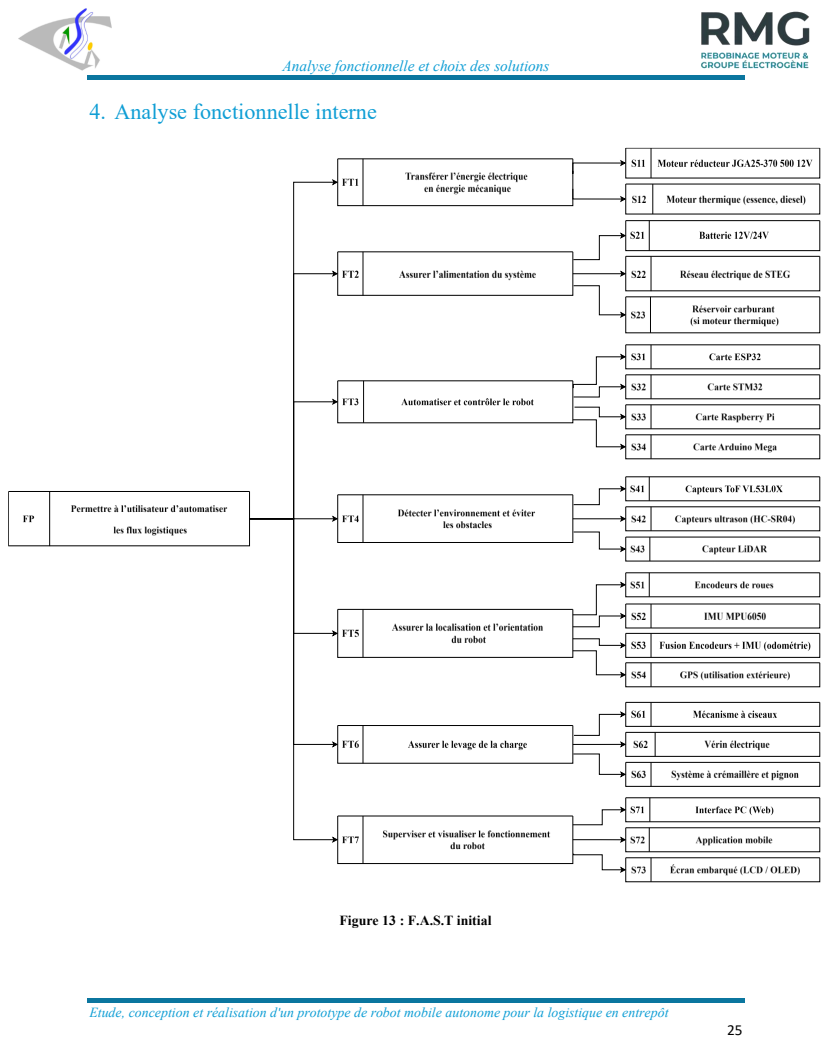
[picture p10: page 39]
Figure 13 : F.A.S.T initial

Analyse fonctionnelle et choix des solutions

Analyse fonctionnelle et choix des solutions

### 4.1. Choix de critère

A partir du cahier de la charge fonctionnelle et l’énoncé des fonctions service on fixe des

critères bien déterminés

Tableau 5 : Tableau valorisation globale
C1 : efficacité

C2 : puissance

C3 : encombrement

C4 : sécurité

C5 : cout

### 4.2. Valorisation globale

Toutes les fonctions de service n’ont pas la même importance du point de vue des

utilisateurs. C’est pourquoi une pondération est attribuée en fonction de critères spécifiques.

Tableau 6 : Tableau d'importance

Dans cette section l’objectif est d’explorer différentes solutions technologiques afin

d’identifier l’option la plus adaptée pour assurer le bon fonctionnement de notre machine tout

en respectant les exigences du cahier des charges :

Note | Intérêt de solution
1 | Douteuse
2 | Moyen
3 | Bien adaptée
K | Importance de la FS
1 | Utile
2 | Nécessaire
3 | Important
4 | Très important
5 | Vitale

Analyse fonctionnelle et choix des solutions

### 4.3. Choix du moteur :

Tableau 7 : Choix du moteur
| K | S1 | S2
Note(N) | Produit (N*K) | Note(N) | Produit (N*K)
C1 | 4 | 3 | 12 | 2 | 8
C2 | 5 | 3 | 15 | 3 | 15
C3 | 2 | 3 | 6 | 1 | 2
C4 | 4 | 3 | 12 | 2 | 8
C5 | 3 | 2 | 6 | 1 | 3
Total | | | 51 | | 36

Après les deux analyses, la 1ère solution se révèle être la plus avantageuse grâce à une

meilleure performance globale elle assure un déplacement optimal de système tout en

respectant les critères établis.

Figure 14 : Les solutions proposées de la fonction technique 1

Analyse fonctionnelle et choix des solutions

### 4.4. Choix de type d’énergie :

Tableau 8 : Choix de type d’énergie
| K | S1 | S2 | S3
Note(N) | Produit (N*K) | Note(N) | Produit (N*K) | Note(N) | Produit (N*K)
C1 | 5 | 3 | 15 | 2 | 10 | 2 | 10
C2 | 5 | 3 | 15 | 3 | 15 | 2 | 10
C3 | 3 | 1 | 3 | 3 | 9 | 1 | 3
C4 | 4 | 3 | 12 | 1 | 4 | 1 | 4
C5 | 3 | 2 | 6 | 2 | 6 | 1 | 3
Total | | | 51 | | 44 | | 30

Après les trois analyses, la 1ère solution se révèle être la plus avantageuse grâce à une

meilleure performance globale elle assure une alimentation optimale de système tout en

respectant les critères établis.

Figure 15 : Les solutions proposées de la fonction technique 2

Analyse fonctionnelle et choix des solutions

### 4.5. Choix de la carte de commande :

Tableau 9 : Choix de la carte de commande
| K | S1 | S2 | S3 | S4
Note (N) | Produit (N*K) | Note (N) | Produit (N*K) | Note (N) | Produit (N*K) | Note (N) | Produit (N*K)
C1 | 4 | 3 | 12 | 1 | 4 | 1 | 4 | 1 | 4
C2 | 1 | 3 | 3 | 3 | 3 | 3 | 3 | 3 | 3
C3 | 2 | 3 | 6 | 2 | 4 | 1 | 2 | 1 | 2
C4 | 4 | 2 | 8 | 3 | 12 | 2 | 8 | 3 | 12
C5 | 3 | 3 | 9 | 3 | 9 | 1 | 3 | 2 | 6
Tot al | | | 38 | | 32 | | 20 | | 27

Après les quatre analyses, la 1ère solution se révèle être la plus avantageuse grâce à sa

connectivité intégrée (Wi-Fi/Bluetooth), sa compacité et son faible coût, tout en restant

performant et en respectant les critères établis.

Figure 16 : Les solutions proposées de la fonction technique 3

Analyse fonctionnelle et choix des solutions

### 4.6. Choix du système de détection :

Tableau 10 : Choix du système de détection
| K | S1 | S2 | S3
Note(N) | Produit (N*K) | Note(N) | Produit (N*K) | Note(N) | Produit (N*K)
C1 | 4 | 3 | 12 | 2 | 8 | 3 | 12
C2 | 5 | 3 | 15 | 1 | 5 | 3 | 15
C3 | 2 | 3 | 6 | 2 | 4 | 1 | 2
C4 | 4 | 3 | 12 | 2 | 8 | 3 | 12
C5 | 3 | 3 | 9 | 3 | 9 | 1 | 3
Total | | | 54 | | 34 | | 44

Après les trois analyses, la 1ère solution se révèle être la plus avantageuse grâce à sa

précision de mesure, sa rapidité de détection et sa faible consommation d’énergie tout en

respectant les critères établis.

Figure 17 : Les solutions proposées de la fonction technique 4

Analyse fonctionnelle et choix des solutions

### 4.7. Choix du système de cartographie :

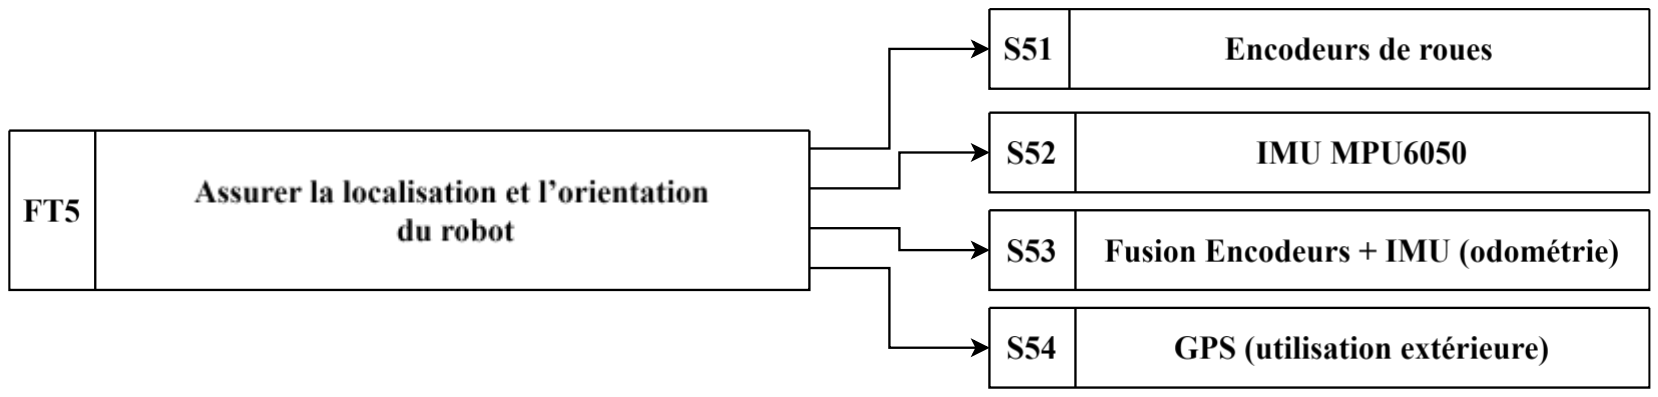
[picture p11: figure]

Tableau 11 : Choix du système de cartographie
| K | S1 | S2 | S3 | S4
Note (N) | Produit (N*K) | Note (N) | Produit (N*K) | Note (N) | Produit (N*K) | Note (N) | Produit (N*K)
C1 | 4 | 2 | 8 | 2 | 8 | 3 | 12 | 3 | 12
C2 | 5 | 2 | 10 | 2 | 10 | 3 | 15 | 3 | 15
C3 | 2 | 3 | 5 | 3 | 5 | 3 | 6 | 1 | 2
C4 | 4 | 1 | 4 | 2 | 8 | 3 | 12 | 3 | 12
C5 | 3 | 3 | 9 | 3 | 9 | 3 | 9 | 1 | 3
Tot al | | | 36 | | 40 | | 54 | | 44

Après les quatre analyses, la 3eme solution se révèle être la plus avantageuse grâce à sa

meilleure précision de localisation, sa capacité de fusion des données et sa fiabilité dans des

environnements variés, tout en garantissant une bonne estimation de la position et en respectant

les critères établis.

Figure 18 : Les solutions proposées de la fonction technique 5

Analyse fonctionnelle et choix des solutions

### 4.8. Choix du mécanisme de levage :

Tableau 12 : Choix du mécanisme de levage
| K | S1 | S2 | S3
Note(N) | Produit (N*K) | Note(N) | Produit (N*K) | Note(N) | Produit (N*K)
C1 | 5 | 3 | 15 | 2 | 10 | 2 | 10
C2 | 4 | 3 | 12 | 2 | 8 | 3 | 12
C3 | 3 | 3 | 9 | 1 | 3 | 3 | 9
C4 | 4 | 3 | 12 | 2 | 8 | 2 | 8
C5 | 2 | 3 | 6 | 3 | 6 | 3 | 6
Total | | | 54 | | 35 | | 45

Après les trois analyses, la 1ère solution se révèle être la plus avantageuse grâce à sa

simplicité mécanique, sa stabilité et sa capacité à supporter des charges importantes tout en

respectant les critères établis.

Figure 19 : Les solutions proposées de la fonction technique 6

Analyse fonctionnelle et choix des solutions

### 4.9. Choix du système de supervision :

Tableau 13 : Choix du système de supervision

| K | S1 | S2 | S3
Note(N) | Produit (N*K) | Note(N) | Produit (N*K) | Note(N) | Produit (N*K)
C1 | 3 | 3 | 9 | 3 | 9 | 2 | 6
C2 | 3 | 3 | 9 | 3 | 9 | 3 | 9
C3 | 1 | 3 | 3 | 3 | 3 | 2 | 6
C4 | 4 | 3 | 12 | 2 | 8 | 3 | 12
C5 | 2 | 3 | 6 | 1 | 2 | 2 | 4
Total | | | 39 | | 31 | | 37

Après les trois analyses, la 1ère solution se révèle être la plus avantageuse grâce à sa facilité

d’accès, sa compatibilité avec plusieurs plateformes et sa simplicité de mise en œuvre, tout en

respectant les critères établis.

Figure 20 : Les solutions proposées de la fonction technique 7

Analyse fonctionnelle et choix des solutions

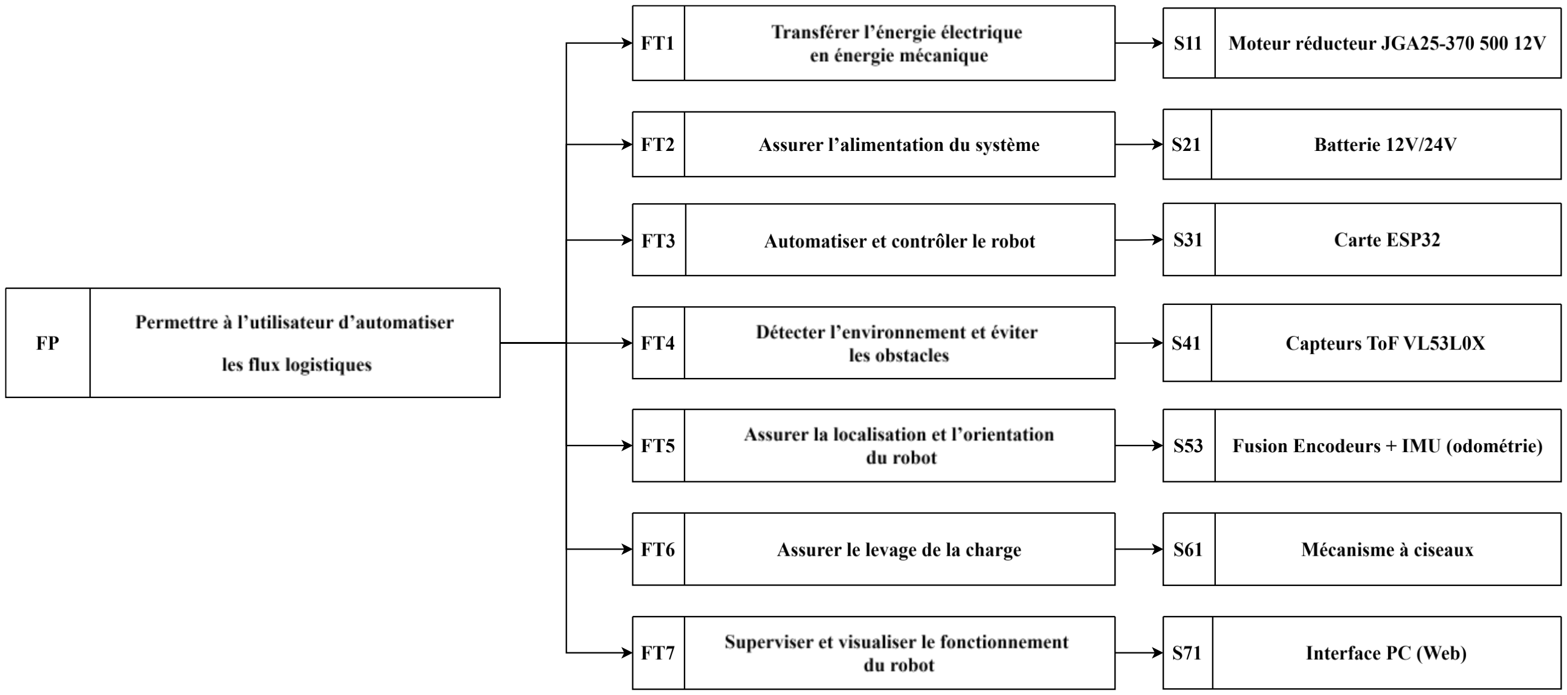
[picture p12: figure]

Etude, conception et réalisation d'un prototype de robot mobile autonome pour la logistique en entrepôt

Figure 21 : FAST final

Analyse fonctionnelle et choix des solutions

## 5. Schéma cinématique

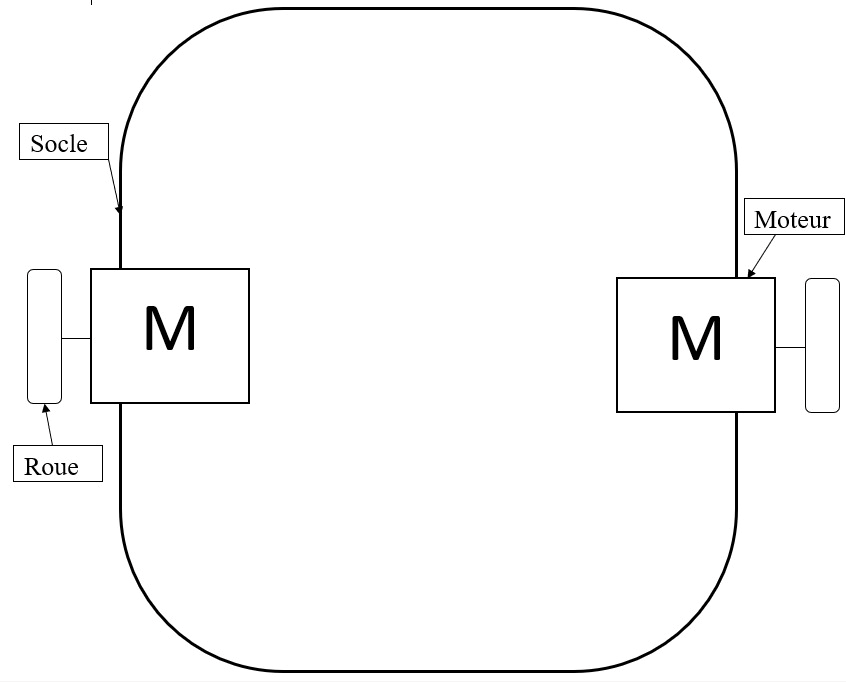
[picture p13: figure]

Figure 22 : Schéma cinématique

## 6. Conclusion

Après l’analyse fonctionnelle, le choix des matériaux a été réalisé en tenant compte des

contraintes techniques, économiques et disponible. Les matériaux sélectionnés assurent une

performance optimale tout en garantissant l’efficacité du robot. Ces choix seront validés à

travers des tests et simulations dans les prochaines étapes du projet.

# CHAPITRE III : Étude et conception

Etude et conception

# CHAPITRE III : Étude et conception

## 1. Introduction

Ce chapitre est consacré à l’étude détaillée et à la conception du robot mobile autonome

développé dans le cadre de ce projet de fin d’études. Il couvre l’architecture globale du système,

la conception électronique basée sur l’ESP32-S3, la conception mécanique réalisée sous

SolidWorks, ainsi que la conception logicielle embarquée. Une section est également consacrée

au dimensionnement mécanique et énergétique du système afin de valider la faisabilité du

prototype.

## 2. Architecture générale du système

L'architecture générale du robot mobile autonome conçu dans ce projet est organisée autour

de six sous-systèmes fonctionnels interdépendants, orchestrés par le microcontrôleur ESP32-

S3. Chaque sous-système répond à une ou plusieurs fonctions de service identifiées dans le

cahier des charges. La figure ci-dessous présente la vue d'ensemble de cette architecture.

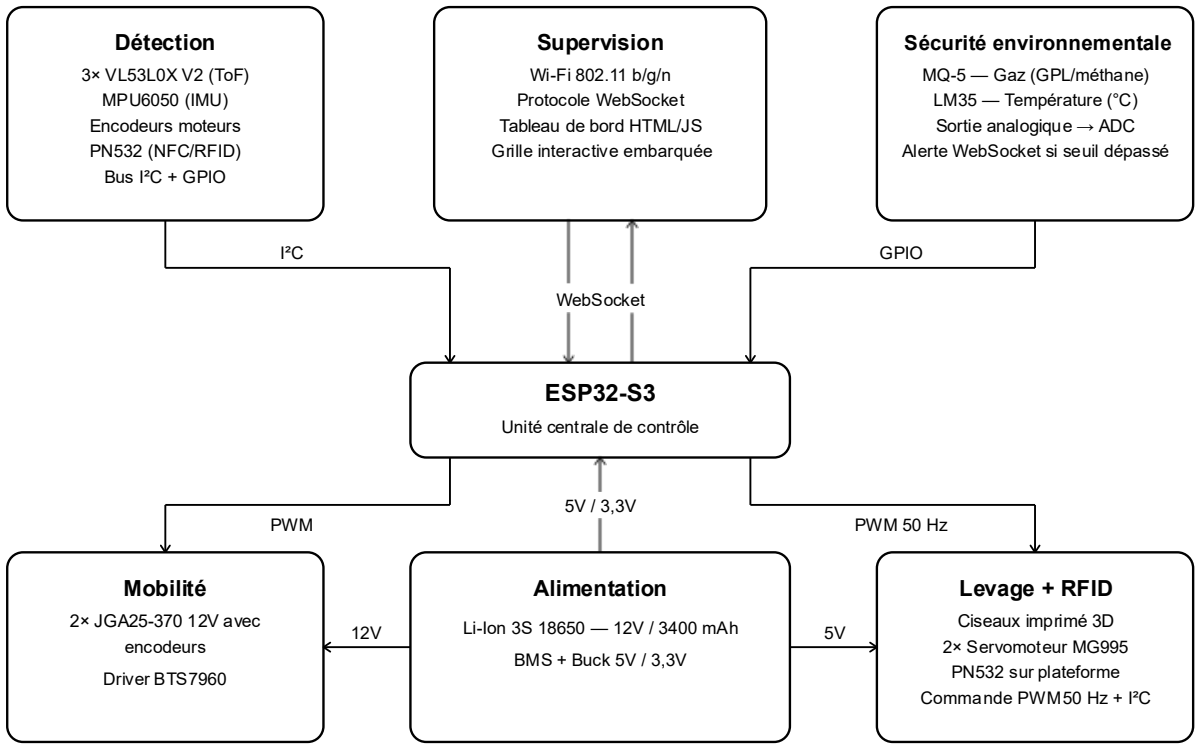
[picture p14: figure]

Figure 23 : Vue des six sous-systèmes

Etude et conception

Le microcontrôleur ESP32-S3 est le nœud central du système. Il exécute simultanément six tâches

FreeRTOS sur ses deux cœurs Xtensa LX7 cadencés à 240 MHz, assurant la gestion temps réel de

la navigation, du contrôle moteur PID, de la communication WebSocket, du levage, de la lecture

RFID et de la sécurité environnementale.

### 2.1. Présentation des six sous-systèmes

### 2.1.1. Système de mobilité

Ce sous-système est responsable du déplacement physique du robot. Il repose sur une

architecture de traction différentielle : deux moteurs DC JGA25-370 12V à réducteur

intégré sont montés symétriquement sur le châssis, chacun pilotant une roue motrice

indépendante. La différence de vitesse entre les deux roues permet d'effectuer des rotations

sur place et des virages précis, sans aucun mécanisme de braquage. Les signaux PWM

générés par l'ESP32-S3 sont amplifiés par un driver BTS7960 qui fournit le courant

nécessaire aux moteurs (jusqu'à 2A par canal). Les encodeurs magnétiques intégrés dans

chaque moteur restituent un signal de retour numérique (signaux A et B en quadrature)

permettant de mesurer la vitesse et le déplacement angulaire de chaque roue avec une

précision de ±1°.

### 2.1.2. Système de détection et de navigation

La navigation autonome du robot repose sur la fusion de trois sources de

données complémentaires :

- Trois capteurs ToF VL53L0X V2 disposés en éventail (gauche, frontal, droit) :

détection des obstacles et cartographie des murs par temps de vol laser infrarouge,

portée jusqu'à 2 m, précision ±2 mm, fréquence d'échantillonnage 50 Hz.

Communication via bus I²C partagé. Les trois capteurs partagent l'adresse par défaut

0x29 ; leur initialisation séquentielle au démarrage (via les broches XSHUT) leur

assigne des adresses distinctes 0x30, 0x31 et 0x32, permettant leur cohabitation sur un

même bus

- IMU MPU6050 : centrale inertielle 6 axes (accéléromètre 3 axes + gyroscope 3 axes),

utilisée pour la correction de cap en boucle fermée et la détection des dérapages

éventuels. Communication via bus I²C à l'adresse fixe 0x68

Etude et conception

- Encodeurs magnétiques intégrés aux moteurs JGA25-370 : odométrie différentielle

pour l'estimation incrémentale de la position et du déplacement du robot, avec une

résolution effective de 0,136 mm/impulsion en décodage quadrature

La fusion de ces trois sources permet une estimation robuste de la position du robot et

une réaction rapide aux obstacles imprévus, sans nécessiter de capteur LIDAR coûteux.

Cette approche remplace avantageusement une cartographie complexe par un système de

repères physiques simples et fiables, parfaitement adapté aux besoins de RMG.

### 2.1.3. Système de levage

Le mécanisme de levage est un système en ciseaux entièrement fabriqué par

impression 3D en PLA+ noir, matériau choisi pour sa résistance accrue à la flexion par

rapport au PLA standard. Le mécanisme est constitué de deux bras croisés centraux de 130

mm de longueur articulés autour d'un pivot central, complétés par quatre bras de support de

55 mm assurant la liaison à la plateforme de transport et au châssis.

L'actionnement est assuré par deux servomoteurs MG995 montés en opposition de

part et d'autre du mécanisme, synchronisés par signaux PWM à 50 Hz sur GPIO8 et

GPIO20. Chaque servomoteur fournit un couple nominal de 10 kg·cm (≈ 0,98 N·m). Le

montage en opposition permet de répartir équitablement l'effort sur les deux côtés du ciseau

et d'éliminer les jeux mécaniques asymétriques lors du levage en charge.

La plateforme se déplace verticalement de 120 mm (position basse) à 270 mm

(position haute), soit une course utile de 150 mm. Cette course est suffisante pour effectuer

un cycle complet de prise-dépose d'une charge de masse maximale 1 kg, conformément au

cahier des charges.

Un module NFC/RFID PN532 est monté directement sur la face supérieure de la

plateforme de levage, orienté vers le haut. Chaque colis à transporter est équipé d'un tag

RFID (carte MIFARE Classic 13,56 MHz) collé sur sa face inférieure. Ce tag encode

l'identifiant de destination du colis (« A » pour Block A, « B » pour Block B). Lorsqu'un

opérateur pose un colis sur la plateforme, le PN532 lit automatiquement le tag en moins de

200 ms et en déduit à la fois la présence du colis (tag lu = colis présent) et sa destination

Etude et conception

(données du tag = Block A ou Block B). Cette approche résout élégamment deux problèmes

avec un seul capteur :

- Détection de présence du colis (le PN532 lit un tag → colis détecté ; pas de tag →

plateforme vide).

- Identification automatique de la destination (les données du tag indiquent le bloc

cible), éliminant toute intervention manuelle de l'opérateur pour sélectionner la

destination.

Le PN532 communique sur le bus I²C partagé à l'adresse 0x24 (7-bit). Le câblage

I²C entre le PN532 (monté sur la plateforme mobile) et le PCB (fixé au châssis) est réalisé

en câble plat flexible.

### 2.1.4. Système de supervision et communication

La supervision à distance du robot est assurée par une interface web embarquée directement

dans la mémoire Flash de l'ESP32-S3, accessible depuis n'importe quel navigateur du

réseau local. L'ESP32-S3 fonctionne en mode point d'accès Wi-Fi (Access Point), exposant

un SSID dédié (« AMR-ROBOT ») auquel l'utilisateur connecte son smartphone, sa tablette

ou son ordinateur portable.

La communication entre le navigateur et le robot s'effectue via le protocole WebSocket sur

le port 80, mis en œuvre grâce aux bibliothèques AsyncWebServer et AsyncWebSocket

[W6]. Ce choix présente trois avantages décisifs par rapport à une architecture à broker

MQTT externe : (i) aucune dépendance à un serveur tiers ou à un PC additionnel, (ii) latence

d'aller-retour inférieure à 50 ms entre le navigateur et le robot, (iii) bidirectionnalité native

pour le streaming télémétrique en temps réel comme pour l'envoi de commandes.

Le tableau de bord web intègre les fonctionnalités suivantes :

- Affichage en temps réel de la télémétrie : vitesse, cap, distances (gauche, face, droite),

tension batterie, température, concentration en gaz, état du levage.

- Visualisation dynamique de la grille 4×4 : pendant l'exploration, la carte se remplit en

temps réel avec les murs détectés et les cellules visitées. Cette visualisation permet à

l'opérateur de suivre l'avancement de la cartographie.

Etude et conception

- Envoi de commandes manuelles : déclenchement de mission, commande de

levage/abaissement, téléopération directionnelle, arrêt d'urgence logiciel.

### 2.1.5. Système d'alimentation

L'alimentation du robot est assurée par un pack de batteries Li-Ion 18650 monté en 3S

(trois cellules en série), fournissant une tension nominale de 11,1 V (12V pleine charge).

La capacité de 3400 mAh et le courant de décharge maximal de 8A répondent aux besoins

de l'ensemble des actionneurs. Un circuit BMS (Battery Management System) assure la

protection contre les surintensités, la sur-décharge et le déséquilibre des cellules. Un

convertisseur buck (step-down) abaisse la tension à 5V pour alimenter l'ESP32-S3, les

capteurs I²C et le servomoteur MG995

### 2.1.6. Système de sécurité environnementale

Ce sous-système répond directement à la fonction de service FC6 du cahier des

charges (prévention des risques d'incendie par surveillance environnementale). Il s'appuie

sur deux capteurs analogiques connectés aux entrées ADC de l'ESP32-S3, scrutés en

permanence par une tâche FreeRTOS de priorité maximale (niveau 5) toutes les 10

millisecondes :

- Capteur de gaz MQ-5 : détecte la présence de gaz combustibles (GPL, méthane, butane,

gaz naturel) par variation de la résistance de son élément sensible SnO₂ chauffé. Le seuil

d'alerte est paramétré à 300 ppm de GPL, En cas de dépassement, le robot exécute un

arrêt immédiat des actionneurs et publie une alerte critique sur le WebSocket.

- Capteur de température LM35 : capteur linéaire de précision (10 mV/°C), plage −55 °C à

+150 °C, précision ±0,5 °C à 25 °C. Surveille la température ambiante de l'environnement

de travail. Le seuil d'alerte est fixé à 60 °C, valeur correspondant à un échauffement

anormal potentiellement précurseur d'un départ de feu ou d'une défaillance électrique.

Le choix combiné MQ-5 + LM35 vise à détecter les deux précurseurs principaux

d'un incendie en environnement industriel : la présence de gaz combustibles avant ignition,

et l'échauffement anormal de l'environnement ou d'un équipement. Cette approche par

prévention précoce permet d'éviter l'embrasement effectif, contrairement à un capteur de

flamme qui ne déclencherait qu'après inflammation. Elle correspond aux pratiques

industrielles standards en sécurité d'entrepôt.

Etude et conception

### 2.2.Diagramme de flux de données et de signaux

Le schéma suivant détaille les flux de données et de signaux entre les composants lors

du fonctionnement autonome du robot.

Bus I²C : utilisé pour les capteurs numériques (trois VL53L0X V2, MPU6050, PN532). Ce

bus partagé minimise le nombre de broches utilisées tout en garantissant une

communication fiable à 400 kHz.

Entrées analogiques (ADC) : les capteurs MQ-5 et LM35 délivrent une tension

proportionnelle à la grandeur mesurée, échantillonnée par les convertisseurs 12 bits intégrés

à l'ESP32-S3.

Sorties PWM : pilotent les drivers BTS7960 des moteurs JGA25-370 (20 kHz) et les

servomoteurs MG995 du mécanisme de levage (50 Hz).

La communication sans fil avec le tableau de bord est assurée par Wi-Fi via WebSocket, et

les retours des encodeurs en quadrature complètent la chaîne d'acquisition pour l'odométrie.

Cette architecture modulaire garantit un fonctionnement déterministe et une intégration

cohérente entre les sous-systèmes.

Figure 24 : Diagramme de flux de données et de signaux du système

Etude et conception

## 3. Conception électronique

La conception électronique du robot est structurée autour du microcontrôleur ESP32-S3

N16R8, qui constitue le cœur de traitement et de commande du système. Les capteurs et actionneurs

sont interfacés via des bus standardisés : I²C pour les capteurs numériques, ADC pour les signaux

analogiques et PWM pour le pilotage des actionneurs. Cette organisation garantit une architecture

cohérente, modulaire et adaptée aux contraintes du temps réel. La figure associée présente le

schéma de câblage détaillé, illustrant les interconnexions physiques, la distribution des signaux et

la gestion des alimentations.

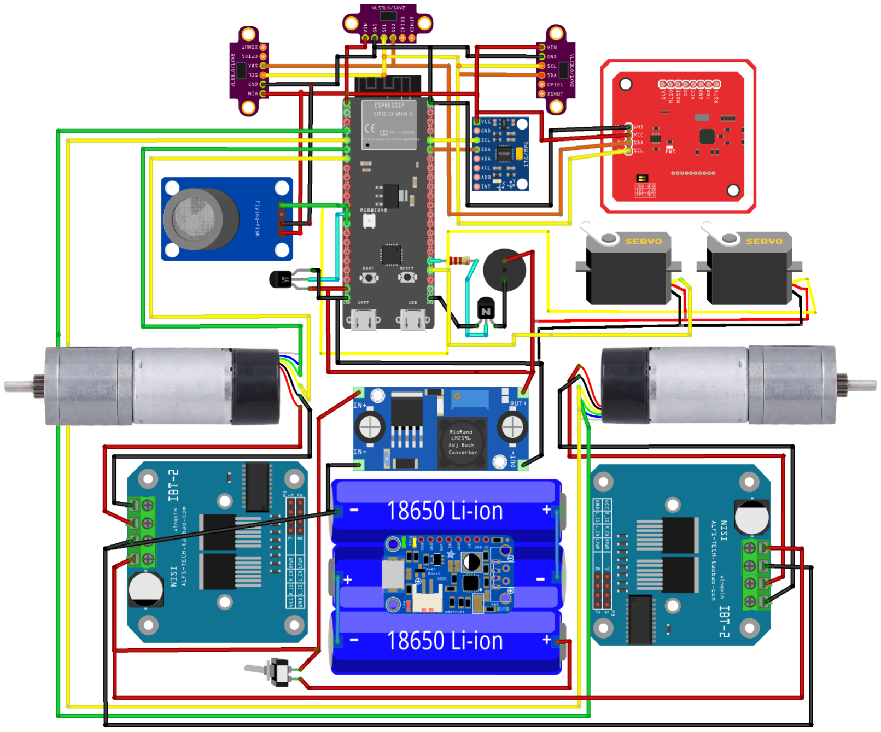
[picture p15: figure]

Figure 25 : Schéma de câblage de robot

Etude et conception

Dans une démarche d’optimisation des performances et de la fiabilité,

ce schéma a été concrétisé par la conception d’une carte électronique

dédiée (PCB) développée en interne.

Cette intégration permet de réduire l’encombrement du système,

d’améliorer l’organisation des connexions et de limiter les erreurs ainsi

que les perturbations électromagnétiques liées aux câblages filaires. Elle

offre également une meilleure robustesse mécanique et électrique, tout en

facilitant la maintenance et le débogage. Cette approche répond ainsi aux

exigences de compacité, de fiabilité et de performance d’un robot mobile

autonome destiné à des applications logistiques.

### 3.1. Description des éléments du système électrique

### 3.1.1. Carte ESP32-S3

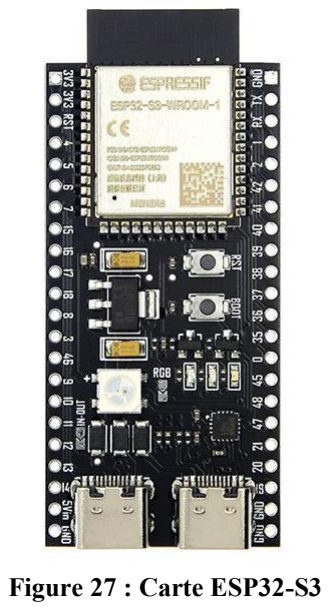
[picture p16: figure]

L’ESP32-S3 N16R8 [9] est un microcontrôleur avancé développé par Espressif Systems,

spécialement conçu pour les applications embarquées nécessitant de hautes performances et

des capacités de traitement étendues. Grâce à son architecture moderne et à ses fonctionnalités

de communication sans fil intégrées, il est largement utilisé dans des domaines tels que la

robotique, | l’intelligence | artificielle | embarquée | et | l’Internet | des | Objets | (IoT).

Son architecture dual-core ainsi que l’intégration de mémoire étendue (Flash et PSRAM) en

Figure 27 : Carte ESP32-S3 | Figure 28 : Schéma carte ESP32-S3

Figure 26 : L’encombrement du système

Etude et conception

font une solution particulièrement adaptée pour le contrôle et la gestion de systèmes robotiques

complexes.

- Caractéristiques techniques principales

L’ESP32-S3 N16R8 se distingue par les caractéristiques suivantes :

Processeur double cœur : Xtensa LX7 32 bits cadencé jusqu’à 240 MHz, offrant un

traitement parallèle performant.

Mémoire étendue : 512 Ko de SRAM interne, 16 Mo de mémoire Flash, 8 Mo de PSRAM

(RAM externe), idéale pour les applications avancées (IA, traitement d’image)

Connectivité sans fil intégrée : Wi-Fi 2,4 GHz (802.11 b/g/n), Bluetooth 5 (BLE)

Grand nombre d’entrées/sorties (GPIO) : Support des interfaces PWM, ADC, SPI, I2C,

UART.

Fonctionnalités avancées : Accélération pour l’intelligence artificielle (instructions

vectorielles), USB natif (OTG), Capteurs intégrés (effet Hall, tactile capacitif selon les

modèles), Gestion énergétique optimisée : adaptée aux systèmes autonomes alimentés par

batterie.

- Fonctionnement dans le système

Dans le cadre de notre robot mobile autonome, l’ESP32-S3 N16R8 joue un rôle central en

assurant plusieurs fonctions essentielles :

Unité de traitement principale : Il assure la gestion globale du système en exécutant les

algorithmes de navigation (A*, Flood Fill), en traitant les données issues des capteurs et en

contrôlant les actionneurs.

Communication sans fil : Il permet la communication avec l’utilisateur ou d’autres

dispositifs via Wi-Fi et Bluetooth, notamment pour la supervision, le contrôle à distance ou

l’échange de données.

Traitement des données capteurs : Il analyse les informations provenant des capteurs

(ultrasons, température, etc.) afin de permettre une prise de décision en temps réel.

Commande des actionneurs : Il génère les signaux de commande (PWM) envoyés aux

drivers moteurs (ex : module de puissance), assurant ainsi un contrôle précis des déplacements

du robot.

Etude et conception

### 3.1.2. Capteur VL53L0X (ToF)

Le VL53L0X est un capteur de distance avancé basé sur la technologie Time-of-Flight

(ToF), développé par STMicroelectronics. Il permet de mesurer la distance avec une grande

précision en utilisant un faisceau laser infrarouge. Grâce à sa rapidité et à sa fiabilité, il est

largement utilisé dans les systèmes robotiques nécessitant une détection précise des obstacles.

Sa technologie basée sur le temps de vol du signal lumineux lui permet de fournir des

mesures indépendantes de la couleur ou de la texture des objets, ce qui le rend particulièrement

adapté aux environnements complexes. [4]

- Caractéristiques techniques principales

Technologie Time-of-Flight (ToF) par laser infrarouge

Portée de mesure : jusqu’à environ 2 mètres

Haute précision (millimétrique)

Figure 29 : Capteur VL53L0X | Figure 30 : Schéma de Brochage du VL53L0X

Figure 31 : Principe de fonctionnement du VL53L0X

Etude et conception

Interface de communication I2C

Faible consommation énergétique

Dimensions compactes

- Fonctionnement dans le système

Dans notre robot mobile autonome, les capteurs VL53L0X assurent :

✓ Détection des obstacles en temps réel

✓ Mesure précise des distances dans plusieurs directions

✓ Contribution à la navigation autonome

✓ Support aux algorithmes de cartographie (Flood Fill)

### 3.1.3. Capteur MPU6050

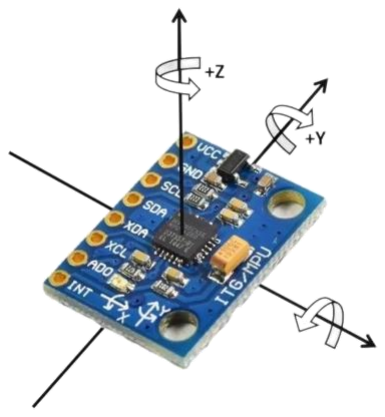
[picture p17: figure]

Le MPU6050 est un capteur inertiel combiné intégrant un accéléromètre et un gyroscope

sur trois axes. Il permet de mesurer les mouvements et l’orientation du robot, ce qui est essentiel

pour assurer la stabilité et améliorer la précision de navigation.

Grâce à son intégration compacte et à sa communication numérique, il est largement utilisé

dans les systèmes embarqués et robotiques. [5]

- Caractéristiques techniques principales

Accéléromètre 3 axes

Figure 32 : Capteur MPU-6050 | Figure 33 : Schéma de Brochage du MPU-6050

Etude et conception

Gyroscope 3 axes

Communication via I2C

Haute précision de mesure

Faible consommation énergétique

Capacité de traitement interne (DMP)

- Fonctionnement dans le système

Dans notre robot, le MPU6050 permet :

✓ La détection des mouvements et rotations

✓ L’amélioration de la stabilité du robot

✓ L’estimation de l’orientation

✓ L’optimisation du contrôle de trajectoire

### 3.1.4. Capteur de gaz MQ-5

Le MQ-5 est un capteur de gaz conçu pour détecter la présence de gaz inflammables tels

que le GPL, le méthane et le butane. Il est couramment utilisé dans les systèmes de sécurité

pour la détection des fuites.

Son fonctionnement basé sur la variation de résistance en présence de gaz permet une

détection fiable et rapide.

- Caractéristiques techniques principales

Détection des gaz combustibles

Sortie analogique et numérique

Figure 35 : Capteur de gaz MQ-5 | Figure 34 : Schéma de Brochage du Capteur MQ-5

Etude et conception

Temps de réponse rapide

Haute sensibilité

Faible coût d’intégration

Compatible avec ESP32 via ADC

- Fonctionnement dans le système

Dans notre robot, le MQ-5 permet :

✓ La détection de fuites de gaz combustibles

✓ La surveillance de l’environnement

✓ Le déclenchement d’alertes de sécurité

✓ L’amélioration de la sécurité environnementale

### 3.1.5. Capteur LM35

Le LM35 est un capteur de température analogique conçu pour mesurer la température

ambiante avec une grande précision. Il est largement utilisé dans les systèmes électroniques et

embarqués pour la surveillance thermique et le contrôle de sécurité.

Son fonctionnement basé sur une tension de sortie proportionnelle à la température permet

une mesure simple, fiable et rapide.

- Caractéristiques techniques principales

Mesure de température en °C

Sortie analogique linéaire

Haute précision de mesure

Faible consommation d’énergie

Figure 37 : Capteur de température LM35 | Figure 36 : Schéma de Brochage du LM35

Etude et conception

Temps de réponse rapide

Compatible avec ESP32 via ADC

- Fonctionnement dans le système
Dans notre robot, le LM35 permet :
✓ La surveillance de la température ambiante
✓ La détection d’une élévation anormale de température ✓ Le déclenchement d’alertes de sécurité thermique
✓ L’amélioration de la sécurité du système électronique

### 3.1.6. Module driver moteur BTS7960

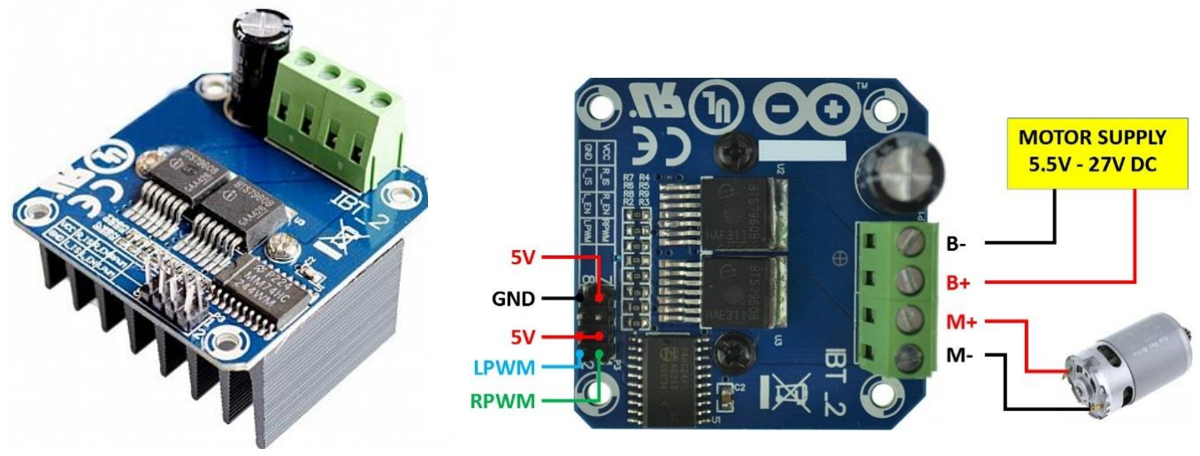
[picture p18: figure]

Le BTS7960 est un driver de puissance utilisé pour le contrôle des moteurs à courant continu du robot. Il permet de piloter la vitesse et le sens de rotation des moteurs grâce à des signaux PWM.

Grâce à sa capacité de courant élevée, il est particulièrement adapté aux applications robotiques nécessitant une puissance importante et une commande fiable des moteurs.

- Caractéristiques techniques principales

Commande bidirectionnelle des moteurs

Contrôle par PWM

Courant maximal jusqu’à 42 A

Compatible moteurs DC 12 V

Protection thermique intégrée

Protection contre les surintensités et courts-circuits

Figure 39 : Module driver moteur BTS7960 Figure 38 : Schéma de Brochage du BTS7960

Etude et conception

- Fonctionnement dans le système

Dans notre robot, le BTS7960 permet :

✓ Le contrôle de vitesse des moteurs

✓ Le contrôle du sens de rotation

✓ L’alimentation des moteurs à forte puissance

✓ La protection du système de commande et des moteurs

### 3.1.7. Servomoteur MG995

Le MG995 est un servomoteur à couple élevé utilisé pour le mécanisme de levage du robot. Grâce à ses engrenages métalliques et à sa forte capacité de charge, il est particulièrement adapté aux applications robotiques nécessitant un contrôle précis et une puissance mécanique importante. Il permet de positionner le système de levage avec précision pour assurer les opérations de chargement et de dépôt [8].

- Caractéristiques techniques principales

Couple élevé jusqu’à 10 kg·cm (à 4,8 V) / 13 kg·cm (à 6 V)

Rotation contrôlée sur environ 180°

Commande par signal PWM

Alimentation 4,8 V – 7,2 V

Engrenages métalliques haute résistance

Temps de réponse rapide et bonne précision

- Fonctionnement dans le système
Figure 41 : Servomoteur MG995 | Figure 40 : Schéma de Brochage du MG995

Etude et conception

Dans notre robot, le MG995 permet :

✓ Le levage de la plateforme de transport

✓ L’abaissement du mécanisme de chargement

✓ Le positionnement précis du système de levage

✓ L’automatisation des opérations de chargement et dépôt

### 3.1.8. Module NFC/RFID PN532

Le PN532 est un module de communication NFC/RFID fonctionnant à une fréquence de 13,56 MHz. Il permet la lecture et l’identification de cartes RFID compatibles ISO 14443A, notamment les cartes MIFARE Classic. Grâce à sa communication rapide et fiable, il constitue une solution efficace pour l’identification de repères physiques dans les systèmes robotiques autonomes. [6]

- Caractéristiques techniques principales

Communication NFC/RFID 13,56 MHz

Compatible ISO 14443A et MIFARE Classic

Communication via bus I²C

Lecture rapide et fiable des tags RFID

Faible consommation énergétique

Portée de lecture de quelques centimètres

- Fonctionnement dans le système

Dans notre robot, le PN532 permet :

Figure 43 : Module NFC/RFID PN532 | Figure 42 : Schéma de Brochage du PN532

Etude et conception

✓ L’identification des zones Block A et Block B

✓ Le déclenchement automatique des actions

✓ L’amélioration de la navigation logique du robot

### 3.1.9. Régulateur abaisseur LM2596

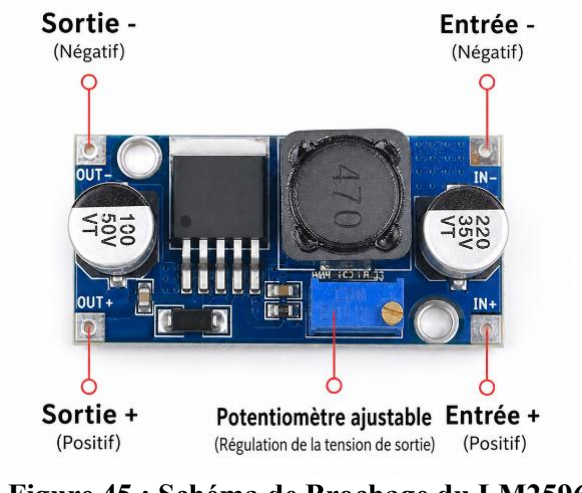
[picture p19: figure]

Le LM2596 est un convertisseur DC-DC abaisseur utilisé pour convertir la tension provenant de la batterie vers des niveaux compatibles avec les composants électroniques du robot. Grâce à son excellent rendement énergétique et à sa capacité de fournir un courant élevé, il constitue une solution fiable pour l’alimentation des systèmes embarqués.

- Caractéristiques techniques principales

Convertisseur DC-DC abaisseur

Tension de sortie ajustable

Courant de sortie jusqu’à 3 A

Rendement élevé jusqu’à 92 %

Protection thermique intégrée

Faible échauffement

- Fonctionnement dans le système

Dans notre robot, le LM2596 permet :

✓ La conversion de la tension batterie

✓ L’alimentation stable de l’ESP32-S3

✓ L’alimentation des capteurs et modules

Figure 44 : Régulateur abaisseur LM2596 | Figure 45 : Schéma de Brochage du LM2596

Etude et conception

✓ L’amélioration de l’efficacité énergétique

### 3.1.10. Moteur JGA25-370 12V 500 RPM avec encodeur

Le JGA25-370 est un moteur à courant continu équipé d’un réducteur métallique et d’un encodeur incrémental intégré. Il combine vitesse, couple et précision, ce qui le rend particulièrement adapté aux robots mobiles autonomes nécessitant un contrôle précis du déplacement et de la trajectoire.

- Caractéristiques techniques principales

Moteur DC 12 V

Vitesse nominale 500 RPM

Réducteur métallique intégré

Encodeur incrémental double canal

Commande compatible PWM

Bon couple et haute stabilité de rotation

- Fonctionnement dans le système

Dans notre robot, ce moteur permet :

✓ Le déplacement du robot

✓ Le contrôle précis de la vitesse

✓ L’estimation de la distance parcourue

✓ L’amélioration de la précision de navigation

Figure 47 : Moteur JGA25-370 12V 500 RPM avec encodeur Figure 46 : Schéma de Brochage du moteur

Etude et conception

### 3.1.11. Batterie Li-ion 18650 Samsung 3400 mAh avec BMS 3S

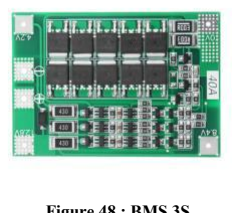
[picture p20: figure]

L’alimentation du robot repose sur des cellules lithium-ion 18650 Samsung assemblées en configuration 3S afin de fournir une source d’énergie stable et rechargeable. Cette architecture permet d’obtenir une tension adaptée aux moteurs et aux systèmes électroniques du robot. Un module BMS (Battery Management System) est intégré afin d’assurer la protection, l’équilibrage et la sécurité des cellules pendant la charge et la décharge. [7]

- Caractéristiques techniques principales

Cellules Li-ion Samsung 18650 Capacité de 3400 mAh par cellule Courant de décharge jusqu’à 8 A Configuration 3S (11,1 V nominal) BMS de protection intégrée

- Fonctionnement dans le système

Dans notre robot, cette alimentation permet :

✓ L’alimentation des moteurs et actionneurs

✓ L’alimentation stable de l’électronique embarquée

✓ La protection contre surcharge et décharge profonde

✓ Une autonomie adaptée aux missions du robot

Figure 49 : Support Batterie Figure 50 : Batterie Li-ion 18650
Samsung 3400 mAh 8A | Figure 48 : BMS 3S

Etude et conception

## 4. Conception mécanique

### 4.1. Présentation de système sur le logiciel « SolidWorks »

SolidWorks est un logiciel de conception assistée par ordinateur (CAO) développé par

Dassault Systèmes. Il permet la modélisation 3D, la simulation et la gestion de données

techniques. Il offre aussi des outils pour concevoir des pièces, des assemblages et des plans

techniques avec précision. Il inclut également des fonctionnalités d'analyse et de simulation

pour évaluer la résistance, la durabilité et les performances des conceptions. SolidWorks est un

outil indispensable pour les ingénieurs et concepteurs, facilitant le passage de l'idée à la

réalisation technique.

### 4.2. Conception du robot

La structure mécanique du robot a été conçue et modélisée sous SolidWorks afin de garantir

une architecture compacte, robuste et adaptée aux contraintes de déplacement autonome. Le

châssis principal adopte une forme rectangulaire réalisée en aluminium léger, permettant de

réduire la masse totale du système tout en assurant une rigidité mécanique suffisante pour

supporter les différents composants électroniques et la charge utile.

Figure 51 : Interface SolidWorks

Etude et conception

Les moteurs JGA25-370 sont montés symétriquement de part et d’autre du châssis afin

d’assurer une propulsion différentielle stable et précise. Une roue folle est intégrée à l’avant et

à l’arrière du robot pour améliorer l’équilibre et la stabilité lors des déplacements.

En complément de la structure en aluminium, plusieurs éléments ont été réalisés par

impression 3D en PETG, notamment les supports de fixation, les interfaces mécaniques et le

cadre supérieur du robot. Cette approche permet une grande flexibilité de conception, une

réduction des coûts de fabrication ainsi qu’une personnalisation rapide des pièces mécaniques

selon les besoins du système.

Figure 52 : Châssis principal | Figure 53 : Dimensionnement de châssis principal

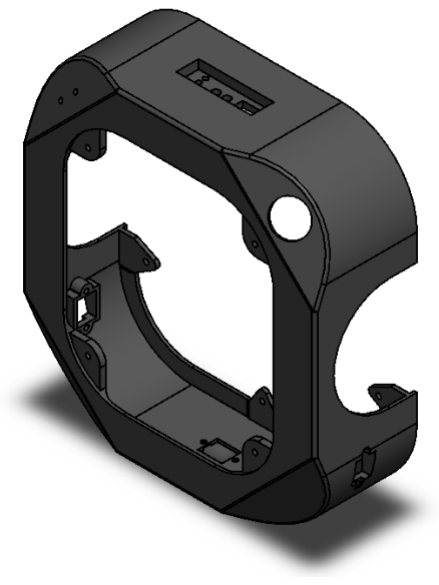
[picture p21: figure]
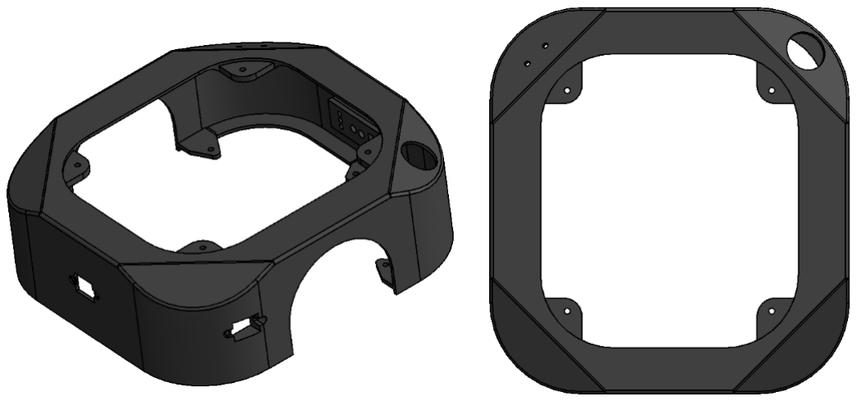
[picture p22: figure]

Figure 54 : Le cadre supérieur du robot.

Etude et conception

### 4.3. Conception du mécanisme de levage

Le robot intègre un mécanisme de levage de type

ciseaux permettant de soulever et d’abaisser la plateforme

de transport. Ce mécanisme a été entièrement conçu sous

SolidWorks puis fabriqué par impression 3D en PETG afin

d’obtenir une structure légère, compacte et facilement

reproductible.

La modélisation mécanique a permis de vérifier les

interférences entre les différentes pièces, de valider le

mouvement cinématique du mécanisme et d’optimiser les

dimensions avant la phase de fabrication physique.

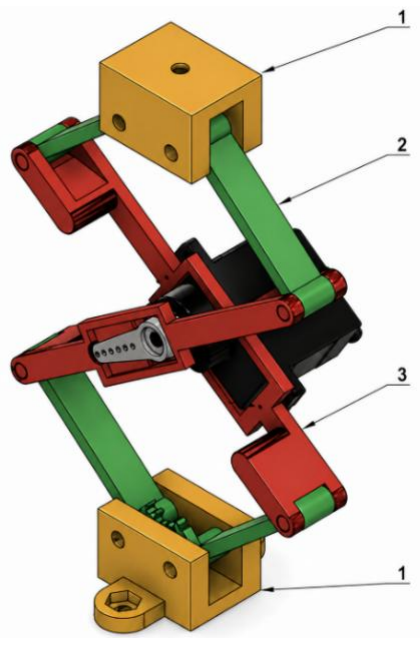
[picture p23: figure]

Le système est actionné par un servomoteur MG995 à couple élevé, capable de fournir

jusqu’à 10 kg·cm, assurant ainsi la force nécessaire au levage de la charge. Le mouvement est

transmis mécaniquement au système de ciseaux afin de convertir la rotation du servomoteur en

déplacement vertical de la plateforme.

Figure 57 : Bras gauche (2) | Figure 61 : Bras droit (2) | Figure 60 : Support haut/bas (1)

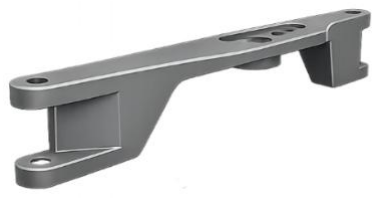
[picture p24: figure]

Figure 56 : Pièce centrale inférieure (3) | Figure 58 : Pièce centrale
| supérieure (3)

Figure 59 : Base de fixation

Figure 55 : Modélisation mécanique

Etude et conception

### 4.4. Conception du support de la maquette

Afin de réaliser l’environnement d’expérimentation du robot, une maquette modulaire de

type 4×4 a été conçue à partir de panneaux MDF. Cette structure est composée de plusieurs

éléments assemblés permettant de reproduire les différentes zones de circulation et de

navigation du robot.

Pour assurer la liaison mécanique entre les différentes parties de la maquette, plusieurs

pièces de connexion ont été conçues et fabriquées par impression 3D en PLA+, Ces éléments

permettent de fixer solidement les panneaux MDF entre eux tout en garantissant un alignement

précis de la structure.

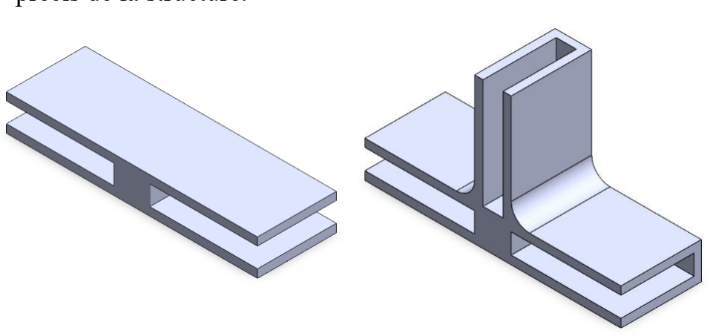
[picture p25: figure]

Cette solution offre une meilleure modularité, facilite le montage et le démontage de la

maquette, et améliore la stabilité globale de l’environnement de test utilisé pour la validation

du système robotique.

Figure 62 : Panneaux MDF | Figure 63 : Maquette 4×4
Figure 66 : Connecteur droit | Figure 65 : Connecteur en T | Figure 64 : Connecteur d’angle

Etude et conception

## 5. Conception logicielle

La conception logicielle du robot mobile autonome repose sur une architecture multicouche

développée entièrement en C++ sous Arduino IDE, en exploitant les capacités temps réel du

microcontrôleur ESP32-S3 [9]. Cette architecture est structurée en trois couches distinctes : la

couche matérielle (HAL — Hardware Abstraction Layer), la couche applicative embarquée

basée sur FreeRTOS [W2], et la couche de supervision distante via le protocole WebSocket

[W6]. Chaque couche communique avec les couches adjacentes via des interfaces bien définies,

garantissant la modularité, la maintenabilité et l'extensibilité du code embarqué [W2].

### 5.1. Organisation des tâches

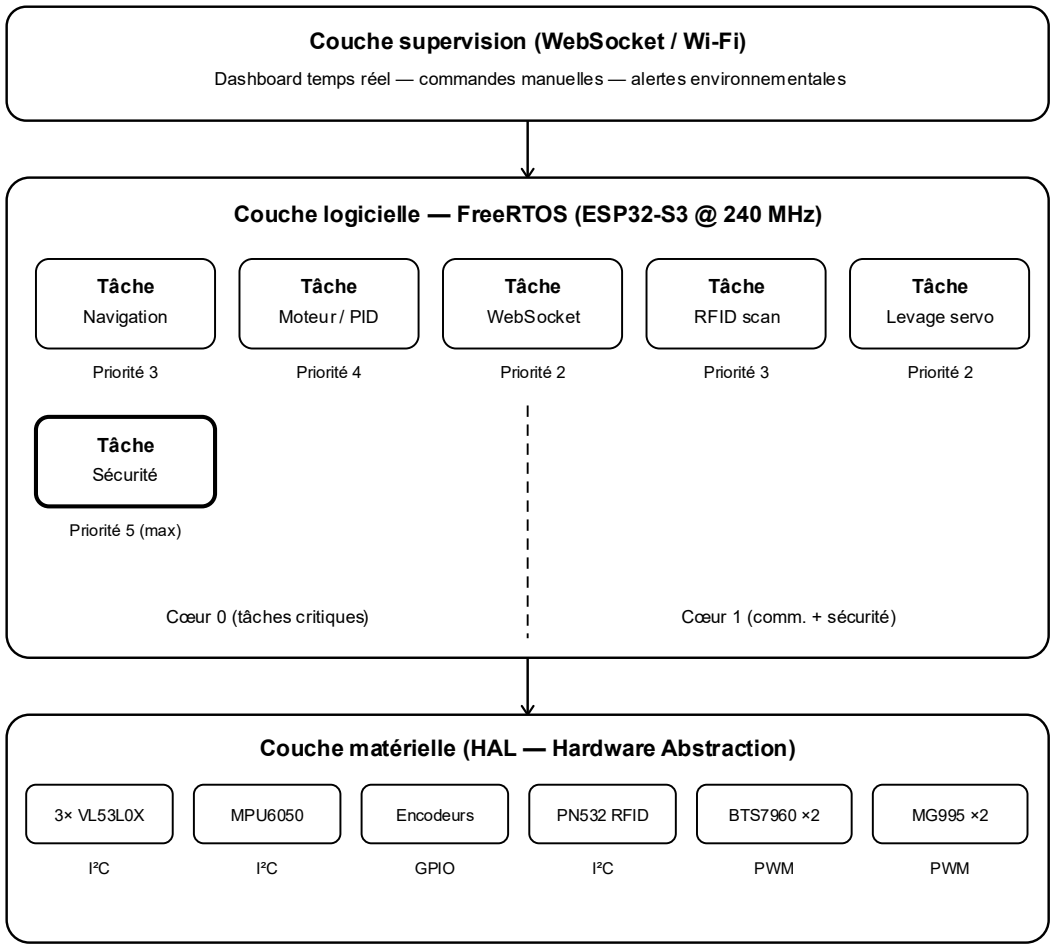
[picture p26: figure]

Figure 67 : Architecture logicielle multicouche du robot

Etude et conception

Le système d'exploitation FreeRTOS gère l'exécution concurrente des six tâches

applicatives. Chaque tâche est affectée à un cœur spécifique et se voit attribuer une priorité

déterminant son ordre de préemption en cas de conflit de ressources. Le tableau ci-dessous

récapitule l'organisation complète des tâches :

Tableau 14 : Organisation des tâches

Tâche | Cœur | Priorité | Période | Rôle principal
Navigation | Cœur 0 | 3 | 50 ms | Flood Fill + odométrie différentielle + fusion capteurs
Moteur / PID | Cœur 0 | 4 | 20 ms | Commande PWM BTS7960 + lecture encodeurs
WebSocket | Cœur 1 | 2 | 100 ms | Publication télémétrie + réception commandes Dashboard
RFID | 1 | 3 | 500 ms | Lecture PN532 sur lifter → détection colis + destination
Levage servo | Cœur 1 | 2 | Evénement | Commande PWM servos MG995 (montée/descente)
Sécurité env. | Cœur 1 | 5 (max) | 10 ms | Lecture MQ-5, LM35 - arrêt d'urgence

La tâche de sécurité environnementale bénéficie de la priorité maximale (niveau 5). Elle

interroge le capteur de gaz MQ-5 et le capteur de température LM35 toutes les 10

millisecondes. Si la concentration en gaz dépasse le seuil de 300 ppm ou si la température

excède 60 °C, elle déclenche un arrêt immédiat de tous les actionneurs et publie une alerte

critique sur le topic robot/alerte.

### 5.2. Asservissement par correcteur PID

Le cahier des charges impose une précision d'arrêt de ±1 cm et des rotations fidèles à

90°. En commande boucle ouverte sur le cap, l'asymétrie naturelle entre les deux moteurs

JGA25-370 (couples résistants, frottements, réponses en vitesse) ainsi que les perturbations

externes (variations de tension batterie, micro-glissements) génèrent une dérive angulaire

cumulative incompatible avec ces exigences. Il est donc nécessaire de mettre en place un

Etude et conception

système asservi en boucle fermée sur l'orientation, exploitant la mesure de cap fournie par

le gyroscope du MPU6050.

### 5.2.1. Modélisation et schéma fonctionnel

Le processus G(p) regroupe l'ensemble {drivers BTS7960 + moteurs + châssis}, dont

l'entrée est la commande différentielle Δω et la sortie l'angle de cap ψ. Le correcteur C(p)

élabore Δω à partir de l'erreur ε(p) = ψ*(p) − ψ(p). Le retour étant unitaire, la fonction de

transfert en boucle fermée s'écrit, d'après la formule de Black :

F(p) =

ψ(p)
ψ ∗ (p)

=

C(p) · G(p)
1 + C(p) · G(p)

### 5.2.2. Correcteur PID et choix retenu

La loi de commande générale d'un correcteur Proportionnel-Intégral-Dérivé s'écrit : u(t) = Kp · ε(t) + Ki · ∫ ε(τ)dτ + Kd · dε(t)/dt

Chacune des trois actions joue un rôle spécifique : P améliore la rapidité et réduit

l'erreur statique ; I annule l'erreur statique en régime permanent ; D apporte un effet

amortissant qui réduit le dépassement. Pour notre application, une structure

Proportionnelle-Dérivée (PD) a été retenue, c'est-à-dire un PID dont le gain intégral est

volontairement maintenu nul (Ki = 0). Le rôle de chaque action et la justification de ce

choix sont détaillés ci-après.

Kp ≠ 0 : Elle constitue le cœur de la correction : la commande différentielle Δω est

rendue proportionnelle à l'erreur de cap. Plus le robot s'écarte de sa consigne, plus la

correction appliquée est forte. Le réglage de ce gain résulte d'un compromis : trop faible, il

laisse subsister une dérive résiduelle ; trop élevé, il provoque un comportement oscillatoire,

le robot « louvoyant » de part et d'autre de sa trajectoire.

Kd ≠ 0 : Elle a été introduite pour amortir la réponse et supprimer les oscillations

observées en correction purement proportionnelle, notamment dans les portions de

trajectoire dépourvues de murs latéraux de référence. Le terme dérivé agit comme un frein

anticipatif qui s'oppose à la vitesse de variation de l'erreur. Un point essentiel de

l'implémentation doit être souligné : la dérivée de l'erreur n'est pas obtenue par dérivation

numérique de la position opération qui amplifierait le bruit mais directement à partir de la

vitesse angulaire mesurée par le gyroscope. En effet, pour une consigne constante par

morceaux,

Etude et conception

dε/dt = − dψ/dt = − ωz,

où ωz est la vitesse de rotation fournie nativement par le MPU6050. Cette formulation

procure un terme dérivé propre et lève l'objection classiquement opposée à l'action dérivée

sur capteur inertiel

Ki = 0 : Le gain intégral a délibérément été maintenu nul, pour deux raisons

complémentaires. D'une part, le cap de consigne est recalé à chaque rotation sur une valeur

absolue (multiple de 90°) ; aucune erreur statique durable ne subsiste donc qui justifierait

une intégration. D'autre part et c'est l'argument déterminant l'intégration du léger biais

résiduel du gyroscope provoquerait un phénomène d'emballement de l'intégrale
Δω(t) = Kp · ε(t) + Kd · (dε/dt) = Kp · ε(t) − Kd · ωz(t)

Les gains ont été déterminés expérimentalement, par une procédure de réglage itératif

inspirée de la méthode de Ziegler-Nichols et adaptée à un système à dynamique lente et

bien amortie. La démarche, conduite directement sur le robot et sa maquette, s'est déroulée

en quatre étapes :

Réglage du proportionnel seul (Kd = 0). Le gain Kp a été augmenté progressivement jusqu'à obtenir une correction franche de la trajectoire. À Kp = 5,0, le robot suivait sa

consigne mais présentait un comportement oscillatoire marqué dans les zones sans mur, le

terme proportionnel réagissant trop brutalement aux écarts.

Réduction du proportionnel. Kp a été ramené à 3,0 afin d'adoucir la réaction et de placer

le système sous le seuil d'oscillation entretenue, au prix d'un léger dépassement résiduel

destiné à être traité par l'action dérivée.

Introduction et réglage du dérivé. Le gain Kd a été augmenté à partir de zéro jusqu'à

l'annulation des oscillations résiduelles. La valeur Kd = 0,8 réalise le meilleur compromis :

amortissement complet du louvoiement, sans ralentissement notable de la réponse ni

réintroduction de bruit, la dérivée provenant directement du gyroscope.

Figeage et validation. Le jeu de gains (Kp = 3,0 ; Kd = 0,8 ; Ki = 0) a été figé puis

soumis à une campagne de validation sur dix essais consécutifs de déplacement et de

rotation.

Le tableau ci-dessous récapitule les paramètres finaux de l'asservissement d'orientation.

Etude et conception

Tableau 15 : Paramètres de l'asservissement d'orientation

Paramètre | Valeur | Rôle
Gain proportionnel Kp | 3,0 | Amplitude de la correction différentielle Δω
Gain dérivé Kd | 0,8 | Amortissement anti-oscillation, issu de ωz (gyroscope)
Gain intégral Ki | 0 | Désactivé pour éviter l'emballement sur la dérive gyroscopique
Période d'échantillonnage Te | 20 ms | Exécution par la tâche temps réel Moteur/PID (Cœur 0, prio. 4)

L'asservissement a été validé sur dix essais consécutifs de déplacement et de rotation sur la maquette, selon le protocole décrit au chapitre Validation et tests :

Tableau 16 : Résultats de validation de l'asservissement d'orientation

Critère | Mesuré | Spécifié | Conformité
Précision d'arrêt (ligne droite) | ± 0,8 cm | ± 1 cm | Conforme
Précision angulaire (rotation 90°) | ± 1,5° | ± 2° | Conforme

Les deux critères satisfont les exigences du cahier des charges, la précision d'arrêt mesurée (±0,8 cm) dépassant même la spécification (±1 cm). Ces résultats valident la pertinence de la structure PD retenue : l'action proportionnelle assure le redressement de la trajectoire, tandis que l'action dérivée alimentée directement par la vitesse angulaire d'un gyroscope préalablement étalonné garantit un comportement amorti et exempt d'oscillation, parfaitement adapté à la dynamique du robot comme aux caractéristiques du capteur inertiel.

### 5.3. Gestion de la batterie et retour station

La tension de la batterie est mesurée en continu par la tâche de sécurité via l'ADC de

l'ESP32-S3. Le seuil de déclenchement du retour à la station de recharge est fixé à 20% de la

capacité résiduelle, correspondant à une tension de 9,9 V (3,3 V par cellule Li-Ion). Lorsque ce

seuil est atteint, la tâche de navigation reçoit un signal d'interruption et redirige le robot vers

les coordonnées RFID de la station de recharge mémorisées lors de la cartographie.

### 5.4. Communication et supervision

La supervision à distance repose sur une architecture WebSocket entièrement embarquée.

L'ESP32-S3 expose un point d'accès Wi-Fi local (SSID « AMR-ROBOT ») auquel se connecte

directement le terminal de supervision de l'opérateur. Le serveur web embarqué (bibliothèque

AsyncWebServer) sert sur le port 80 une page d'interface HTML/JavaScript stockée en mémoire
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

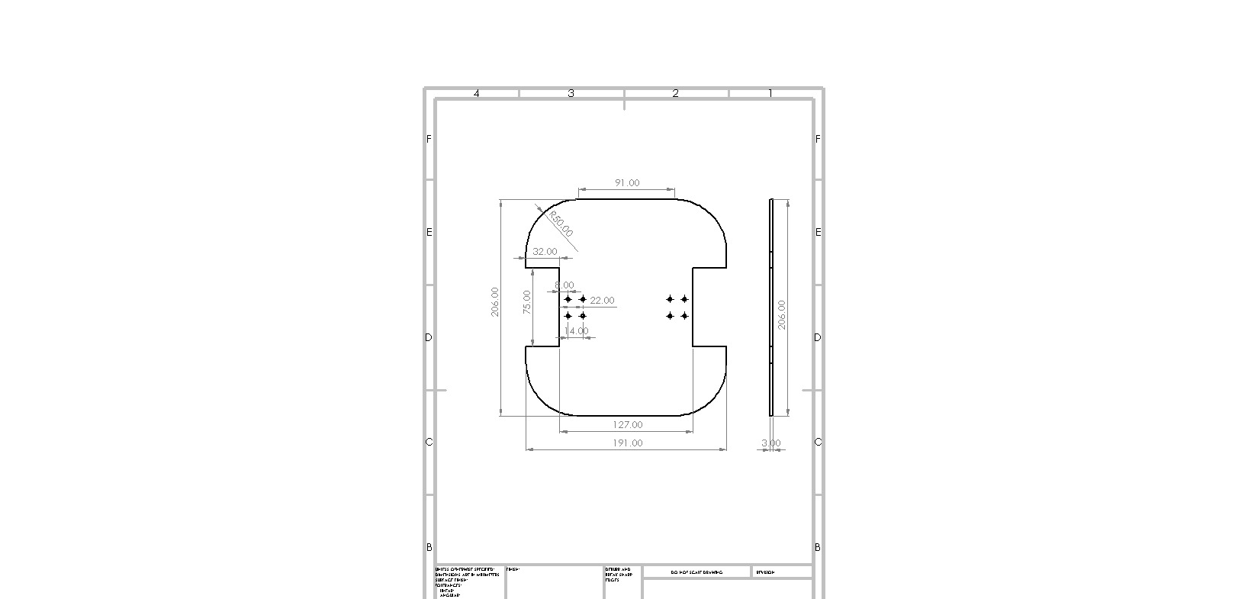
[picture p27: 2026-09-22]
3D FILES/CHASSIS.JPG

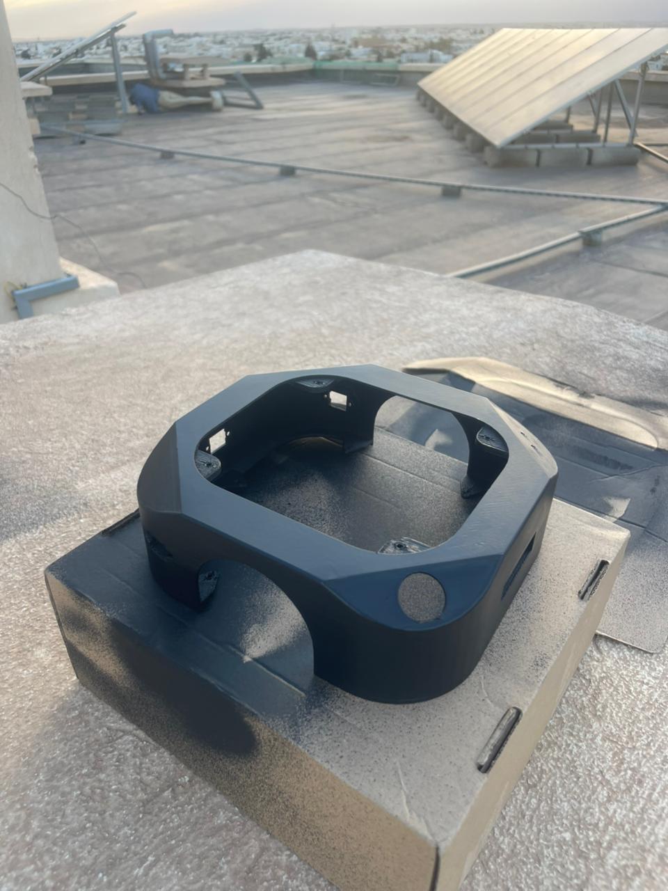
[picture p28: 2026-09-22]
Photos/WhatsApp Image 2026-05-19 at 1.59.06 PM.jpeg

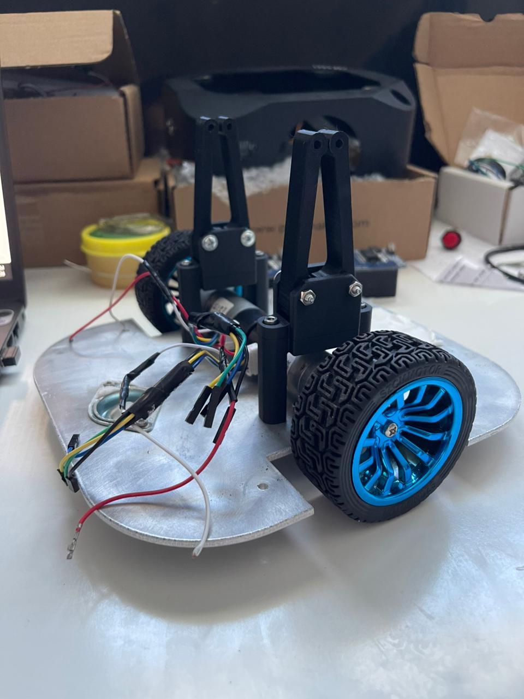
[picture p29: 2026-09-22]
Photos/WhatsApp Image 2026-05-26 at 2.25.33 PM.jpeg

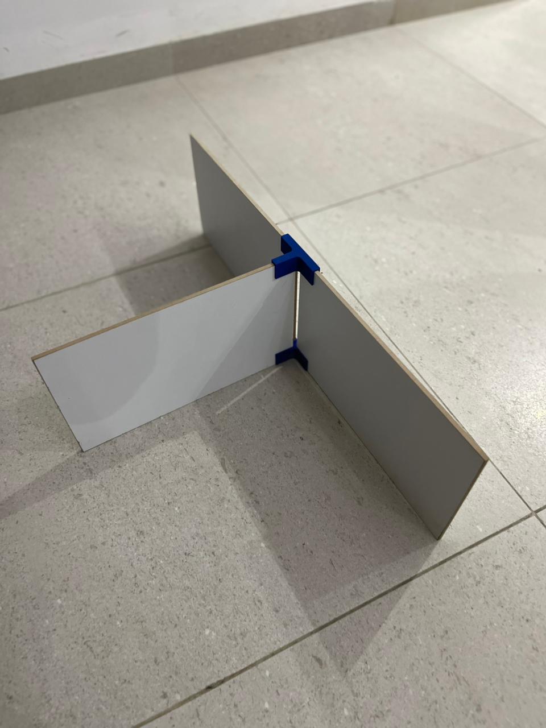
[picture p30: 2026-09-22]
Photos/WhatsApp Image 2026-04-14 at 8.51.27 PM.jpeg

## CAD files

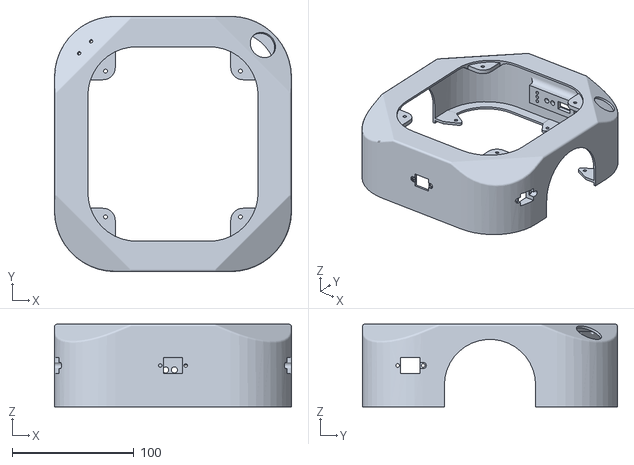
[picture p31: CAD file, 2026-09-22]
3D FILES/CADRE.STL
195.0 x 210.0 x 68.0

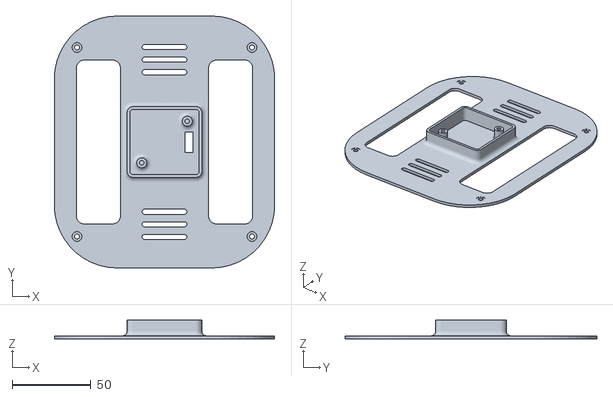
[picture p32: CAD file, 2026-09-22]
3D FILES/COUVRE.STL
140.0 x 160.0 x 12.0

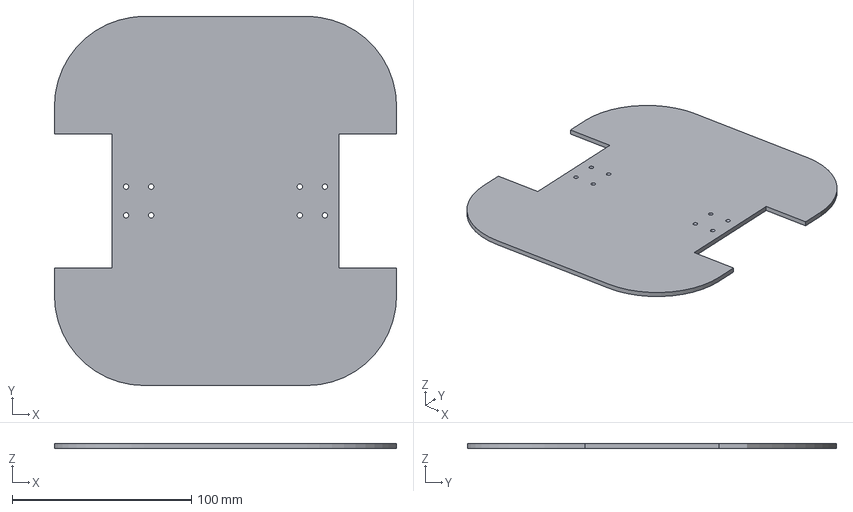
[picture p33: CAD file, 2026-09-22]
3D FILES/CHASSIS_ALUMINUM.3MF
191.0 x 206.0 x 3.00 mm

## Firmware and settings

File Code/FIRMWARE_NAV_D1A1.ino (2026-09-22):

/* =====================================================================
   AMR — FIRMWARE COMPLET (pré-PN532)   [core 3.x]
   ---------------------------------------------------------------------
   OTA + ToF + Servos + MPU + Encodeurs filtrés + Dashboard complet

   *** ENREGISTREMENT MÉTHODE B (taps alternés) ***
   - 1er tap court : démarre, pousse la 1ère LIGNE droite
   - tap court     : fin ligne -> tourne le VIRAGE
   - tap court     : fin virage -> pousse la ligne suivante
   - ... alternance LIGNE <-> VIRAGE
   - tap LONG (2s) : termine l'enregistrement
   Rejeu : bouton START du dashboard (ou tap long quand pas en enreg)

   Librairies : VL53L0X (Pololu), ESP32Servo
   WiFi "AMR-ROBOT" / "amr12345" — Dashboard http://192.168.4.1
   OTA : Outils -> Port -> "AMR-OTA at 192.168.4.1" (mdp amr12345)
   ===================================================================== */

#include <Wire.h>
#include <WiFi.h>
#include <ESPmDNS.h>
#include <ArduinoOTA.h>
#include <WebServer.h>
#include <VL53L0X.h>
#include <ESP32Servo.h>
#include "page_html.h"

/* ============== Broches ============== */
#define ENC_L_A 5
#define ENC_L_B 4
#define ENC_R_A 6
#define ENC_R_B 7
#define I2C_SDA 1
#define I2C_SCL 2
#define MPU_ADDR 0x68
#define BTN_PIN 47
#define BUZZER  21

#define L_FOR  11
#define L_BACK 10
#define R_FOR  17
#define R_BACK 18

#define XSHUT_L 12
#define XSHUT_F 13
#define XSHUT_R 14
#define SERVO_L  8
#define SERVO_R 20

#define LED_RED    36
#define LED_GREEN  38
#define LED_ORANGE 16

#define GYRO_AXIS 0x47

/* ============== Constantes ============== */
const char* AP_SSID = "AMR-ROBOT";
const char* AP_PASS = "amr12345";
const char* OTA_HOSTNAME = "AMR-OTA";
const char* OTA_PASS = "amr12345";

const int PWM_FREQ = 1000, PWM_RES = 8;
const int PWM_REJEU = 70;
const long MARGE_IMP = 18;

/* ============== Buzzer ============== */
void bip(int duree, int nombre = 1, int pause = 120) {
  for (int i = 0; i < nombre; i++) {
    digitalWrite(BUZZER, HIGH); delay(duree); digitalWrite(BUZZER, LOW);
    if (i < nombre - 1) delay(pause);
  }
}

/* ============== LEDs ============== */
volatile bool estopActif = false;
bool apOK = false;
unsigned long lastPoll = 0;   // dernier acces dashboard (LED verte)
volatile int robotCol=0, robotRow=0, robotHeadingMap=0, cellsVisitees=1;  // position carte
volatile bool enMouvement = false;   // true pendant le rejeu (pour dashboard réaliste)
volatile bool demandeNavigation = false;  // mis par /cmd?a=start, traité dans loop()
volatile bool demandeRejeu = false;        // mis par /cmd?a=replay, traité dans loop()

void setupLeds() {
  pinMode(LED_GREEN, OUTPUT);   digitalWrite(LED_GREEN, LOW);
  pinMode(LED_ORANGE,OUTPUT);   digitalWrite(LED_ORANGE,LOW);
  pinMode(LED_RED,   OUTPUT);   digitalWrite(LED_RED,  LOW);
  digitalWrite(LED_GREEN, HIGH); delay(200); digitalWrite(LED_GREEN, LOW);
  digitalWrite(LED_ORANGE,HIGH); delay(200); digitalWrite(LED_ORANGE,LOW);
  digitalWrite(LED_RED,   HIGH); delay(200); digitalWrite(LED_RED,  LOW);
}
void majLeds() {
  bool client = (millis() - lastPoll < 1500);
  digitalWrite(LED_GREEN, client ? HIGH : LOW);
  if (!apOK)         digitalWrite(LED_ORANGE, HIGH);
  else if (!client)  digitalWrite(LED_ORANGE, (millis()/400)%2);
  else               digitalWrite(LED_ORANGE, LOW);
  digitalWrite(LED_RED, estopActif ? ((millis()/200)%2) : LOW);
}

/* ============== Moteurs ============== */
void setMoteurs(int g, int d) {
  if (estopActif) { g = 0; d = 0; }   // ESTOP : coupe les moteurs
  if (g >= 0) { ledcWrite(L_BACK, g);  ledcWrite(L_FOR, 0); }
  else        { ledcWrite(L_BACK, 0);  ledcWrite(L_FOR, -g); }
  if (d >= 0) { ledcWrite(R_FOR, d);   ledcWrite(R_BACK, 0); }
  else        { ledcWrite(R_FOR, 0);   ledcWrite(R_BACK, -d); }
}
void stopMoteurs() { setMoteurs(0, 0); }

/* ============== Servos (lift) ============== */
volatile bool encGele = false;          // déclaré tôt : utilisé par les servos ET les ISR encodeurs
Servo servo1, servo2;
bool servoUp = false;

void servosUp()   {
  encGele = true;                       // gèle les encodeurs (anti-bruit servos)
  servo1.write(95); servo2.write(85);
  delay(500);                           // le temps que le pic de courant passe
  encGele = false;
  servoUp = true;  Serial.println("[SERVO] UP");
}
void servosDown() {
  encGele = true;
  servo1.write(30); servo2.write(30);
  delay(500);
  encGele = false;
  servoUp = false; Serial.println("[SERVO] DOWN");
}

void setupServos() {
  ESP32PWM::allocateTimer(0);
  ESP32PWM::allocateTimer(1);
  servo1.setPeriodHertz(50);
  servo2.setPeriodHertz(50);
  servo1.attach(SERVO_L, 500, 2500);
  servo2.attach(SERVO_R, 500, 2500);
  servosDown();                       // position de repos
}

/* ============== Encodeurs (filtrés contre EMI) ============== */
volatile long encL = 0, encR = 0;
volatile unsigned long lastIsrL = 0, lastIsrR = 0;
const unsigned long MIN_INTERVAL_US = 800;   // <0.8 ms entre impulsions = bruit

void IRAM_ATTR isrL() {
  if (encGele) return;                        // gelé pendant servos
  unsigned long now = micros();
  if (now - lastIsrL < MIN_INTERVAL_US) return; // trop rapide = bruit
  lastIsrL = now;
  if (digitalRead(ENC_L_B)) encL++; else encL--;
}
void IRAM_ATTR isrR() {
  if (encGele) return;
  unsigned long now = micros();
  if (now - lastIsrR < MIN_INTERVAL_US) return;
  lastIsrR = now;
  if (digitalRead(ENC_R_B)) encR++; else encR--;
}
long encMoyenne() { noInterrupts(); long l=encL,r=encR; interrupts(); return (l+r)/2; }

// Remise à zéro des compteurs (utilisée au début de chaque segment / enreg)
void encReset() { noInterrupts(); encL = 0; encR = 0; interrupts(); }

/* ============== MPU ============== */
float gyroZbias = 0, heading = 0;
unsigned long tPrevImu = 0;

int16_t lireGyro() {
  Wire.beginTransmission(MPU_ADDR);
  Wire.write(GYRO_AXIS); Wire.endTransmission(false);
  Wire.requestFrom(MPU_ADDR, 2);
  return (Wire.read() << 8) | Wire.read();
}
float dernierRate = 0;        // vitesse de rotation mémorisée (pour le terme D)

// déclarations anticipées (utilisées par attendreSiEstop avant leur définition)
void lireBouton();
extern WebServer server;

void majCap() {
  unsigned long now = millis();
  float dt = (now - tPrevImu)/1000.0; tPrevImu = now;
  float rate = (lireGyro() - gyroZbias)/131.0;
  dernierRate = rate;         // mémorisé pour vitesseRotation()
  if (fabs(rate) > 0.2) heading += rate * dt;
}

/* ============== ToF VL53L0X ============== */
VL53L0X tofL, tofF, tofR;
uint16_t distL = 9999, distF = 9999, distR = 9999;
bool tofOK_L = false, tofOK_F = false, tofOK_R = false;

void setupToF() {
  // Tous éteints au départ
  pinMode(XSHUT_L, OUTPUT); digitalWrite(XSHUT_L, LOW);
  pinMode(XSHUT_F, OUTPUT); digitalWrite(XSHUT_F, LOW);
  pinMode(XSHUT_R, OUTPUT); digitalWrite(XSHUT_R, LOW);
  delay(20);

  // Gauche -> 0x30
  digitalWrite(XSHUT_L, HIGH); delay(30);
  tofL.setTimeout(200);
  if (tofL.init()) { tofL.setAddress(0x30); tofL.startContinuous(); tofOK_L = true;
                     Serial.println("[ToF] L OK -> 0x30"); }
  else Serial.println("[ToF] L INIT FAIL");

  // Avant -> 0x31
  digitalWrite(XSHUT_F, HIGH); delay(30);
  tofF.setTimeout(200);
  if (tofF.init()) { tofF.setAddress(0x31); tofF.startContinuous(); tofOK_F = true;
                     Serial.println("[ToF] F OK -> 0x31"); }
  else Serial.println("[ToF] F INIT FAIL");

  // Droite -> 0x32
  digitalWrite(XSHUT_R, HIGH); delay(30);
  tofR.setTimeout(200);
  if (tofR.init()) { tofR.setAddress(0x32); tofR.startContinuous(); tofOK_R = true;
                     Serial.println("[ToF] R OK -> 0x32"); }
  else Serial.println("[ToF] R INIT FAIL");
}

void lireToF() {
  if (tofOK_L) distL = tofL.readRangeContinuousMillimeters();
  if (tofOK_F) distF = tofF.readRangeContinuousMillimeters();
  if (tofOK_R) distR = tofR.readRangeContinuousMillimeters();
}

/* ============== Trajet (impulsions) ============== */
/* ============== Enregistrement MÉTHODE B (taps alternés) ==============
   Chaque "segment" mémorise une avance (impulsions) PUIS une rotation (deg).
   - 1er tap court  : démarre, on enregistre une LIGNE (on pousse tout droit)
   - tap court      : fin de la ligne -> on enregistre un VIRAGE (on tourne)
   - tap court      : fin du virage -> nouvelle LIGNE
   - ... alternance LIGNE <-> VIRAGE
   - tap LONG       : termine l'enregistrement complet
   ===================================================================== */
struct Segment { long impulsions; float rotation_deg; };
const int MAX_SEG = 40;
Segment trajet[MAX_SEG];
int  nbSeg = 0;
bool enReg = false;
int  phase = 0;                 // 0 = on enregistre une LIGNE, 1 = on enregistre un VIRAGE
long ligneImpulsions = 0;       // tampon de la ligne en cours
long encDebutSeg = 0; float capDebutSeg = 0;

void demarrerEnreg() {
  nbSeg = 0;
  encReset();
  encDebutSeg = encMoyenne();
  capDebutSeg = heading;
  phase = 0;                    // on commence par une ligne
  ligneImpulsions = 0;
  enReg = true;
  bip(80,1);
  Serial.println(">>> ENREG DEMARRE — pousse la 1ere LIGNE, puis tape pour le virage <<<");
}

// Appelé à chaque TAP COURT pendant l'enregistrement : termine la phase courante
void tapPhase() {
  if (phase == 0) {
    // fin d'une LIGNE -> on stocke les impulsions, on passe au virage
    ligneImpulsions = encMoyenne() - encDebutSeg;
    capDebutSeg = heading;       // référence pour mesurer le virage à venir
    phase = 1;
    bip(60,1);
    Serial.printf("   LIGNE = %ld imp -> maintenant tourne (VIRAGE)\n", ligneImpulsions);
  } else {
    // fin d'un VIRAGE -> on stocke le segment complet (ligne + rotation)
    float rot = heading - capDebutSeg;
    if (nbSeg < MAX_SEG) {
      trajet[nbSeg].impulsions  = ligneImpulsions;
      trajet[nbSeg].rotation_deg = rot;
      nbSeg++;
    }
    encReset();
    encDebutSeg = encMoyenne();
    phase = 0;                   // retour en mode ligne
    bip(60,1);
    Serial.printf("   VIRAGE = %.1f deg -> segment %d enregistre. Pousse la ligne suivante.\n", rot, nbSeg);
  }
}

void arreterEnreg() {
  // termine proprement selon la phase où on se trouve
  if (phase == 0) {
    // on finissait une ligne -> segment avec rotation 0
    long imp = encMoyenne() - encDebutSeg;
    if (nbSeg < MAX_SEG) { trajet[nbSeg].impulsions = imp; trajet[nbSeg].rotation_deg = 0; nbSeg++; }
  } else {
    // on finissait un virage -> stocke ligne précédente + ce virage
    float rot = heading - capDebutSeg;
    if (nbSeg < MAX_SEG) { trajet[nbSeg].impulsions = ligneImpulsions; trajet[nbSeg].rotation_deg = rot; nbSeg++; }
  }
  enReg = false;
  bip(80,2);
  Serial.println(">>> ENREG TERMINE — trajet : <<<");
  for (int i=0;i<nbSeg;i++)
    Serial.printf("  Seg %d : %ld imp, %.1f deg\n",i+1,trajet[i].impulsions,trajet[i].rotation_deg);
}

/* ============== Rejeu (avance avec correction ToF + gyro fallback) ============== */
void avancerImpulsions(long imp) {
  if (imp <= 0) return;
  encReset();                           // <<< reset (ignore bruit pré-segment)
  long cible = imp - MARGE_IMP; if (cible < 0) cible = 0;
  long depart = encMoyenne();
  float capCible = heading;
  const float Kp_gyro = 9.0;
  const float Kp_tof  = 0.5;          // correction par ToF (latérale)
  const uint16_t MUR_PROCHE = 250;    // mm : si distL et distR < 250 → murs détectés

  while ((encMoyenne() - depart) < cible) {
    if (estopActif) { stopMoteurs(); return; }
    majCap();
    lireToF();

    int corr;
    if (tofOK_L && tofOK_R && distL < MUR_PROCHE && distR < MUR_PROCHE) {
      // Correction par ToF : si distL > distR → robot dérive à droite → corrige vers gauche
      int delta = (int)distL - (int)distR;
      corr = (int)(Kp_tof * delta);
    } else {
      // Pas de murs latéraux → correction par gyro
      float erreur = heading - capCible;
      corr = (int)(Kp_gyro * erreur);
    }
    int g = constrain(PWM_REJEU + corr, 0, 255);
    int d = constrain(PWM_REJEU - corr, 0, 255);
    setMoteurs(g, d);
    delay(5);
    ArduinoOTA.handle();
    server.handleClient();   // garde le serveur web reactif (estop, donnees, carte)
  }
  stopMoteurs();
  delay(200);
}

void tournerAngle(float angle_deg) {
  if (fabs(angle_deg) < 3) return;
  majCap();
  float capCible = heading + angle_deg;
  if (angle_deg > 0) {
    while (heading < capCible) {
      if (estopActif) { stopMoteurs(); return; }
      majCap(); setMoteurs(-PWM_REJEU, PWM_REJEU); delay(5); ArduinoOTA.handle();
    }
  } else {
    while (heading > capCible) {
      if (estopActif) { stopMoteurs(); return; }
      majCap(); setMoteurs(PWM_REJEU, -PWM_REJEU); delay(5); ArduinoOTA.handle();
    }
  }
  stopMoteurs();
  delay(200);
}

/* =====================================================================
   NAVIGATION AUTONOME — AVANCE AU GYRO PD (ligne droite pure)
   - Va tout droit en maintenant le cap absolu (PD : P doux + D amortisseur)
   - Filet anti-collision : si un mur latéral < SEUIL_DANGER, petit écart
   - Stop quand distF <= SEUIL_DEVANT (mur devant) OU IMP_PAR_CASE atteint
   ===================================================================== */
const long     IMP_PAR_CASE  = 141;
const uint16_t SEUIL_DEVANT  = 60;     // distF <= 60 -> stop / recale sur la case
const uint16_t APPROCHE_MUR  = 150;    // distF < 150 -> commence à ralentir (plus tôt = plus sûr)
const int      PWM_APPROCHE   = 38;    // vitesse réduite près du mur (plus lent = arrêt net)
const int      PWM_FREIN      = 60;    // freinage actif : impulsion arrière
const int      FREIN_MS       = 45;    // durée du freinage actif (ms)
const uint16_t SEUIL_DANGER  = 58;     // mur latéral plus proche que ça -> on s'écarte (augmenté: évite de toucher)
const int      PWM_NAV        = 70;
const float    KP_CAP         = 3.0;   // P doux (cap)
const float    KD_CAP         = 0.8;   // D amortisseur (anti-zigzag)
const int      ECART_DANGER   = 16;    // correction si mur trop proche (renforcé)

float capCibleAbsolu = 0;

// Conservés comme valeurs neutres (le suivi de mur n'est plus utilisé,
// mais la séquence appelle encore avancerUneCase(MUR_G/MUR_D)).
enum { MUR_G, MUR_D, MUR_AUCUN };

// Si arrêt d'urgence actif : fige le robot (rouge clignote) jusqu'au réarmement.
// Permet de "reprendre depuis la case en cours" : on bloque ici, puis on continue.
void attendreSiEstop() {
  if (!estopActif) return;
  stopMoteurs();
  Serial.println("[ESTOP] Robot fige - attente rearmement...");
  while (estopActif) {
    stopMoteurs();
    digitalWrite(LED_RED, (millis()/200)%2);   // rouge clignote
    lireBouton();                              // permet de réarmer via bouton long
    server.handleClient();                     // permet de réarmer via dashboard
    ArduinoOTA.handle();
    delay(10);
  }
  Serial.println("[ESTOP] Rearme - reprise.");
  bip(60,1);
}

// le paramètre 'mur' n'est plus utilisé pour suivre, gardé pour compat d'appel
// ---------------------------------------------------------------------------
// AVANCE CONTINUE sur 'nCases' cases d'affilée (ligne droite fluide, sans stop).
// - Anti-blocage : si les encodeurs ne bougent plus pendant BLOCAGE_MS alors
//   qu'on pousse, on considère la roue calée -> on termine le segment.
// - Anti-collision renforcé : s'écarte AVANT de toucher (marge augmentée).
// - S'arrête si mur devant (distF) OU objectif d'impulsions atteint.
// ---------------------------------------------------------------------------
const unsigned long BLOCAGE_MS   = 700;    // si 0 impulsion pendant ce temps -> calé
const unsigned long TIMEOUT_CASE = 4500;   // garde-fou par case (ms)

void avancerCases(int nCases, int mur) {
  (void)mur;
  attendreSiEstop();
  encReset();
  long depart   = encMoyenne();
  long objectif = (long)nCases * IMP_PAR_CASE;

  unsigned long tDebut   = millis();
  unsigned long tDernMov = millis();
  long          encPrec  = encMoyenne();

  bool arretSurMur = false;        // pour savoir s'il faut freiner activement

  while (true) {
    if (estopActif) { stopMoteurs(); return; }
    majCap();
    lireToF();

    long parcouru = encMoyenne() - depart;

    // --- PRIORITÉ ABSOLUE : mur frontal (vérifié en premier) ---
    if (tofOK_F && distF <= SEUIL_DEVANT) { arretSurMur = true; break; }
    // fin sur distance parcourue (pas de mur atteint)
    if (parcouru >= objectif) break;

    // --- anti-blocage : détecter une roue calée ---
    long encNow = encMoyenne();
    if (labs(encNow - encPrec) >= 2) {        // ça bouge encore
      encPrec  = encNow;
      tDernMov = millis();
    } else if (millis() - tDernMov > BLOCAGE_MS) {
      Serial.println("[NAV] blocage detecte -> fin de segment");
      break;
    }
    if (millis() - tDebut > TIMEOUT_CASE * nCases) {
      Serial.println("[NAV] timeout segment");
      break;
    }

    // --- cap gyro PD (ligne droite) ---
    float erreurCap = heading - capCibleAbsolu;
    int corr = (int)(KP_CAP * erreurCap + KD_CAP * dernierRate);

    // --- anti-collision renforcé : s'écarter AVANT de toucher ---
    if (tofOK_L && distL < SEUIL_DANGER)      corr += ECART_DANGER;
    else if (tofOK_R && distR < SEUIL_DANGER) corr -= ECART_DANGER;

    // --- ralentissement à l'approche du mur frontal ---
    int pwmBase = PWM_NAV;
    if (tofOK_F && distF < APPROCHE_MUR) {
      pwmBase = map(distF, SEUIL_DEVANT, APPROCHE_MUR, PWM_APPROCHE, PWM_NAV);
      pwmBase = constrain(pwmBase, PWM_APPROCHE, PWM_NAV);
    }

    int g = constrain(pwmBase + corr, 0, 255);
    int d = constrain(pwmBase - corr, 0, 255);
    setMoteurs(g, d);
    delay(5);
    ArduinoOTA.handle();
    server.handleClient();
  }

  // --- FREINAGE ACTIF : tue la glissade pour s'arrêter net (surtout sur mur) ---
  if (arretSurMur) {
    setMoteurs(-PWM_FREIN, -PWM_FREIN);   // impulsion arrière brève
    delay(FREIN_MS);
  }
  stopMoteurs();
  delay(200);
}

// Compat : une seule case = avancerCases(1)
void avancerUneCase(int mur) { avancerCases(1, mur); }

// RECULE de 'nCases' cases (marche arrière), cap maintenu au gyro PD.
// Anti-blocage identique. Pas de capteur ToF arrière -> on se fie aux impulsions.
void reculerCases(int nCases) {
  attendreSiEstop();
  encReset();
  long depart   = encMoyenne();
  long objectif = (long)nCases * IMP_PAR_CASE;
  unsigned long tDernMov = millis();
  long encPrec = encMoyenne();

  while (true) {
    if (estopActif) { stopMoteurs(); return; }
    majCap();

    long parcouru = labs(encMoyenne() - depart);
    if (parcouru >= objectif) break;

    long encNow = encMoyenne();
    if (labs(encNow - encPrec) >= 2) { encPrec = encNow; tDernMov = millis(); }
    else if (millis() - tDernMov > BLOCAGE_MS) { Serial.println("[NAV] blocage recul"); break; }

    // cap PD, mais moteurs en arrière (valeurs négatives)
    float erreurCap = heading - capCibleAbsolu;
    int corr = (int)(KP_CAP * erreurCap + KD_CAP * dernierRate);
    int g = -constrain(PWM_NAV - corr, 0, 255);   // arrière + correction inversée
    int d = -constrain(PWM_NAV + corr, 0, 255);
    setMoteurs(g, d);
    delay(5);
    ArduinoOTA.handle();
    server.handleClient();
  }
  stopMoteurs();
  delay(200);
}

// Tourne de +90 (gauche) ou -90 (droite) en cap ABSOLU continu.
// On incrémente capCibleAbsolu de delta, puis on tourne jusqu'à l'atteindre.
// delta = +90 (gauche) ou -90 (droite).
// Virage précis : approche 2 vitesses + freinage actif. delta = +90 (gauche), -90 (droite)
const int   PWM_VIRAGE_RAPIDE = 70;   // gros du virage
const int   PWM_VIRAGE_LENT   = 32;   // approche finale (faible inertie)
const float ANGLE_LENT        = 25;   // on ralentit dans les 25 derniers degrés
const float MARGE_VIRAGE      = 3;    // on vise 90 - 3 pour compenser l'élan résiduel

void tournerRelatif(int delta) {
  // cible réduite d'une petite marge dans le sens du virage
  float signe = (delta > 0) ? 1.0 : -1.0;
  capCibleAbsolu += delta - signe * MARGE_VIRAGE;
  majCap();

  while (true) {
    if (estopActif) { stopMoteurs(); return; }
    majCap();
    float reste = fabs(heading - capCibleAbsolu);   // degrés restants
    if (reste <= 1.0) break;                         // arrivé (à 1° près)

    // vitesse selon la distance restante : rapide loin, lent près
    int pwm = (reste > ANGLE_LENT) ? PWM_VIRAGE_RAPIDE : PWM_VIRAGE_LENT;

    if (heading < capCibleAbsolu) setMoteurs(-pwm, pwm);   // gauche
    else                          setMoteurs(pwm, -pwm);   // droite
    delay(5);
    ArduinoOTA.handle();
    server.handleClient();   // garde le serveur web reactif (estop, donnees, carte)
  }

  // --- freinage actif : impulsion inverse brève pour stopper net la rotation ---
  float over = heading - capCibleAbsolu;             // de quel côté on finit
  if (fabs(over) > 0.5) {
    if (over > 0) setMoteurs(-PWM_VIRAGE_LENT, PWM_VIRAGE_LENT);  // on a trop tourné à droite -> pousse gauche
    else          setMoteurs(PWM_VIRAGE_LENT, -PWM_VIRAGE_LENT);
    delay(40);
  }
  stopMoteurs();
  delay(250);
}
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
void loop() {
  ArduinoOTA.handle();
  server.handleClient();
  majCap();
  static unsigned long tT = 0;
  if (millis()-tT > 80) { tT = millis(); lireToF(); }
  static unsigned long tL = 0;
  if (millis()-tL > 30) { tL = millis(); majLeds(); }
  lireBouton();

  // lancement de la navigation depuis le dashboard (hors handler web -> pas de réentrance)
  if (demandeNavigation) { demandeNavigation = false; naviguerD1versA1(); }
  if (demandeRejeu)      { demandeRejeu = false;      rejouerTrajet(); }

  if (Serial.available()) {
    char c = toupper(Serial.read());
    if (c=='E') { nbSeg=0; Serial.println("Trajet efface."); }
    else if (c=='S') {  // status
      Serial.printf("ToF L=%u F=%u R=%u cap=%.1f encL=%ld encR=%ld\n",
                    distL,distF,distR,heading,encL,encR);
    }
  }
}
